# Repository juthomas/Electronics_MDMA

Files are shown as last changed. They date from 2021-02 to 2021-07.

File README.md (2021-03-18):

# MEGA DRINKING MACHINA ADVENTURE





<br/>

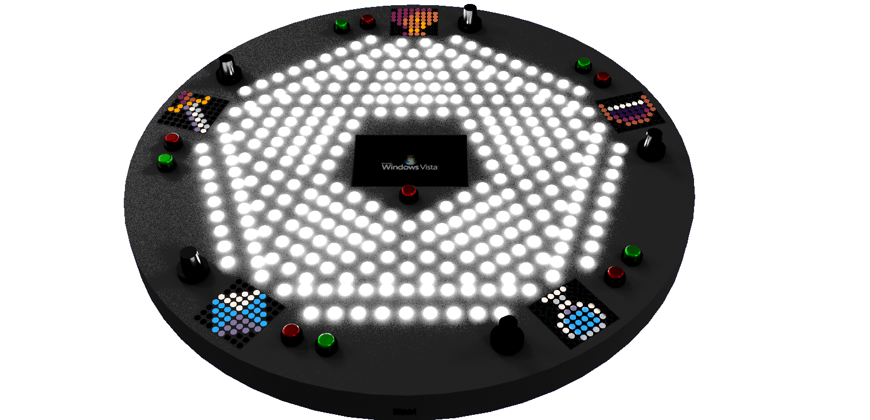
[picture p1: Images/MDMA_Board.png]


__Sommaire__ :
* [Description](#description)
* [Installation](#installation-avr)
* [Usage](#usage)
* [Visual Studio Code Linter](#visual-studio-code-linter)
* [Project Functionalities](#project-functionalities)
  * [Leds Control](#leds-control)
  * [Prerequisites](#prerequisites)
  * [Leds Variables](#leds-variables)
  * [Color Attribution](#color-attribution)
  * [Usefull Functions](#usefull-functions)

<div id='description'/>

## Description

Cet objet à été conçu sur les bases d’un témoignage perturbant à la date du 27 juin 2007 sur le forum ████ par l’utilisateur Chri████4.
Il y fait mention d’un jeu à boire avec ses amis où ils auraient décidé d'invoquer Satan aux alentours de 23h42. La soirée aurait tourné en une cruelle mission de subjugation du malin avec pour seule arme l’alcool en grande quantité qu’ils avaient préparé pour faire la fête. Suite à cette affaire le service d’exorcisme V-696 (avec à sa tête Jean-███II) aurait procédé à une énorme commande de Sobieski. 

À travers le projet Mega Drinking Machina Adventure™ nous voulons faire vivre à nos très chers futurs utilisateurs une simulation familiale de cette aventure hors du commun. Une compilation de jeux à boire allant de 1 à 5 joueurs sera proposée, avec une mise en place intuitive et rapide. Sur batterie, lumineux et facile à transporter, il deviendra votre meilleur outil pour pimenter vos soirées peu importe le contexte.
<div id='installation-avr'/>

## Installation (AVR)

* Debian Based Linux :  
  * Install avr-gcc :  
  `sudo apt-get install gcc-avr binutils-avr avr-libc`
  * Install avr-dude :  
  `sudo apt-get install avrdude`
* Macos Unix :  
  * Install brew (for noobies) :  
  `rm -rf $HOME/.brew && git clone --depth=1 https://github.com/Homebrew/brew $HOME/.brew && export PATH=$HOME/.brew/bin:$PATH && brew update && echo "export PATH=$HOME/.brew/bin:$PATH" >> ~/.zshrc`
  * Install avr-gcc :  
  `brew tap osx-cross/avr`  
  `brew install avr-gcc`
  * Install avr-dude :  
  `brew install avrdude`
<div id='usage'/>

## Usage

* Setup port :  
  `ls /dev/ > /tmp/file1`  
  then connect board  
  `ls /dev/ > /tmp/file2`  
  `diff /tmp/file1 /tmp/file2`  
  will give you the port  
  paste the given port to the `PORT` variable of the makefile

* Upload to board :  
  `make coffee` for build and upload  
  `make debug` for debuging  
  `make help` for other options
<div id='visual-studio-code-linter'/>

## Visual Studio Code Linter

* Install C/C++ extension  
* Configure C/C++ extension for avr :  
  Type `C/C++: Edit Configurations (JSON)` in Command Palette  
  * Linux :  
  Add `"/usr/lib/avr/include/**"` line to includePath  
  * Macos :  
  Add `"/Users/tmp/.brew/Cellar/avr-gcc@9/9.3.0_2/avr/include/**"`  
  on labelec macs  
  or  
  `/System/Volumes/Data/usr/local/Cellar/avr-gcc@9/9.3.0_2/avr/include/**`  
  (on real macs)  
  to includePath.  
  If this line doesnt work find "avr/io.h" file with `find / -name io.h`  
  Add the containing folder to includePath (like Linux method)

<div id='project-functionalities'/>

## Project Functionalities

<div id='leds-control'/>

### Leds Control

<div id='prerequisites'/>

#### Prerequisites
* `ft_pin_mode(led_pin, FT_OUTPUT);`

<div id='leds-variables'/>

#### Leds Variables
* char buffer (size = number of leds * 3)

<div id='color-attribution'/>

#### Color Attribution
  The color format is uint32_t : `0xLLRRGGBB`  
  LL : Luminosity (0x01 to 0xFF, or 0x00 to ignore)  
  RR : Red (0x00 to 0xFF)  
  GG : Green (0x00 to 0xFF)  
  BB : Blue (0x00 to 0xFF)  

<div id='usefull-functions'/>

#### Usefull Functions
* `uint8_t *feed_one_pixel(uint16_t pixel_index, uint8_t *pixels, uint32_t color)`  
  feed the selected pixel with the color
* `led_send_data(51, pixels, pixels_number);`  
  send data to the leds

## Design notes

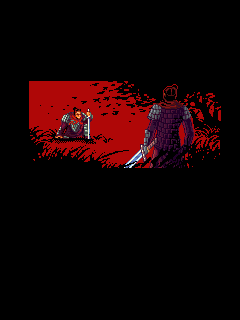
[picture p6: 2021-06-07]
Images/MDMA_Images/Duel.png

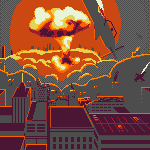
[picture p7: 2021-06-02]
Images/MDMA_Images/background tic.png

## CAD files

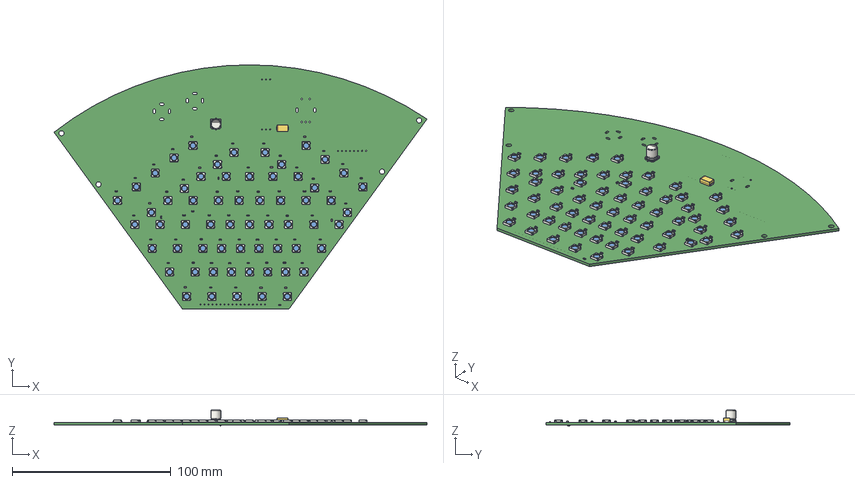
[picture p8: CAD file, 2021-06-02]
MDMA_KICAD_V2/MDMA/MDMA.step
235.0 x 153.9 x 9.85 mm

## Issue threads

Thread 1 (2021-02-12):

Cpu clock & time to execute in assembly

juthomas, 2021-02-12:
In makefile, F_CPU doesn't seems to change somethings, why?
In assembly some actions takes 0.083 us and others 0.1666 us, how and why?
(out %[portb], %[high])

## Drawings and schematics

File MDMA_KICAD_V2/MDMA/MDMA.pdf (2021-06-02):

LED_IN 5 MAT_IN 6 BUT_A 7 BUT_B 8 SW_ENC 9 P1Switch_Pin_out
IRQ 13 MISO 14 MOSI 15 SCK 16 CS 17 VCC_3.3 2 GND 3
VCC_5V 1 ROT_ENC_A 10 ROT_ENC_B 11 RST 12

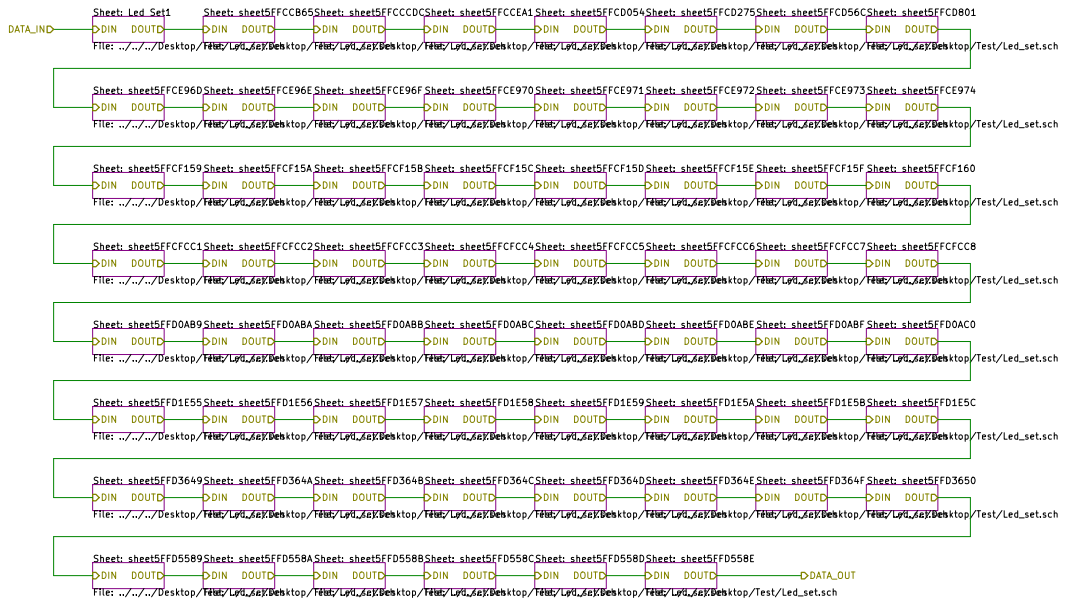
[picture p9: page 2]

Id: 2/66 Title: File: leds.sch Sheet: /leds/

File: Led_set.sch Sheet: /leds/Led Set1/
Id: 3/66 Title:

File: Led_set.sch Sheet: /leds/sheet5FFCCB65/
Id: 4/66 Title:

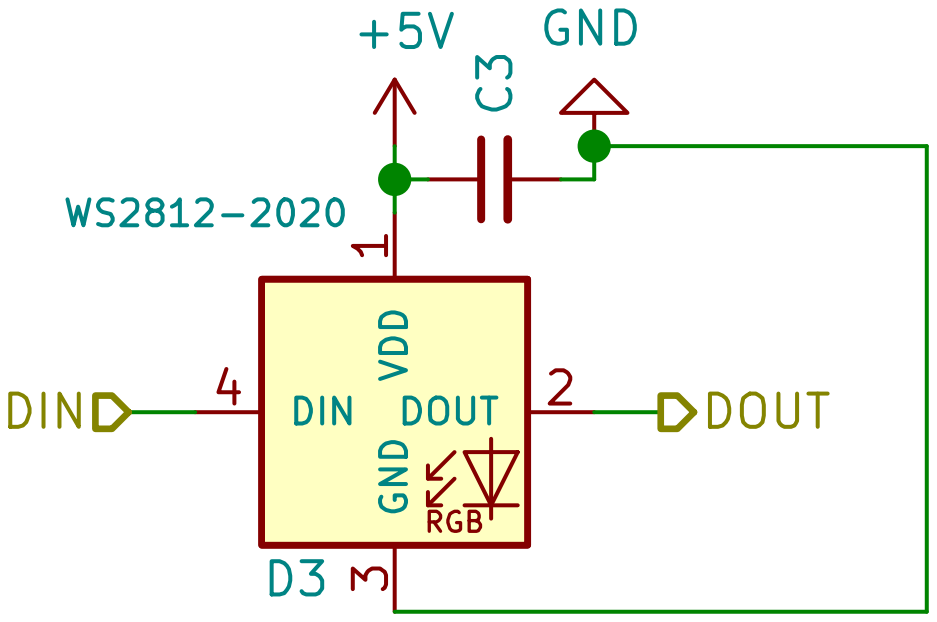
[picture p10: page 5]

File: Led_set.sch Sheet: /leds/sheet5FFCCCDC/
Id: 5/66 Title:

File: Led_set.sch Sheet: /leds/sheet5FFCCEA1/
Id: 6/66 Title:

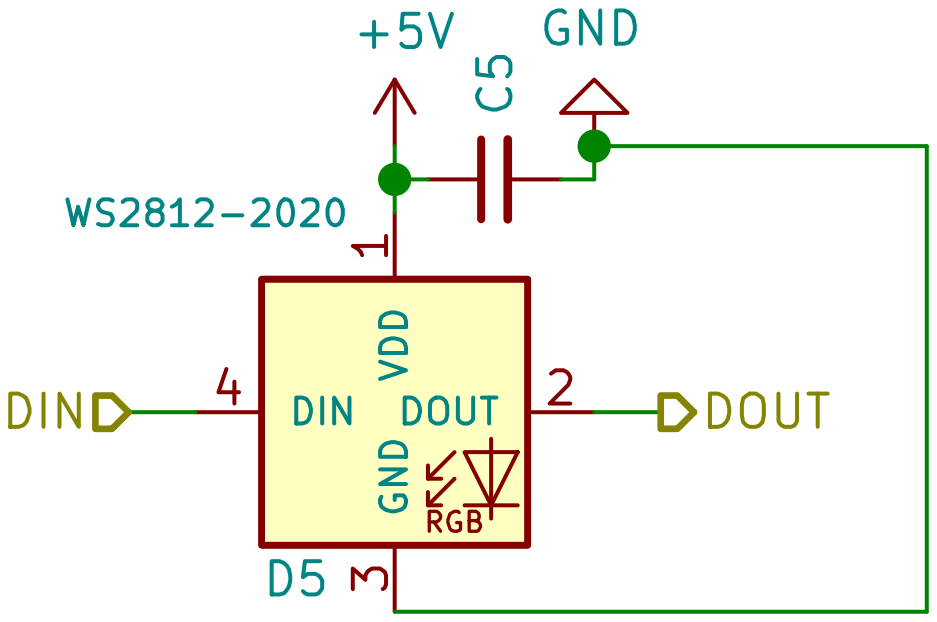
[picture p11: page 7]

File: Led_set.sch Sheet: /leds/sheet5FFCD054/
Id: 7/66 Title:

File: Led_set.sch Sheet: /leds/sheet5FFCD275/
Id: 8/66 Title:

File: Led_set.sch Sheet: /leds/sheet5FFCD56C/
Id: 9/66 Title:

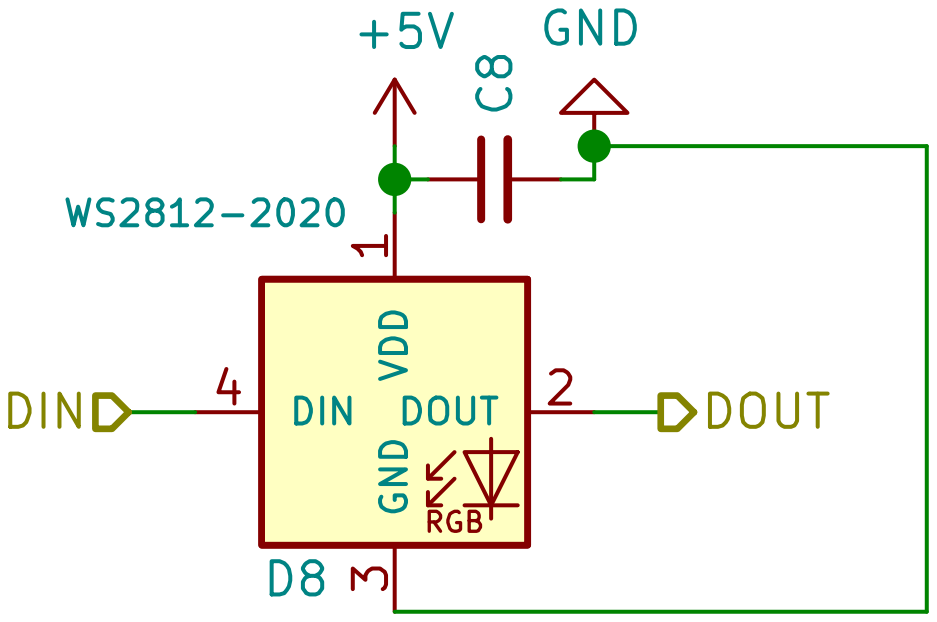
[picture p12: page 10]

File: Led_set.sch Sheet: /leds/sheet5FFCD801/
Id: 10/66 Title:

File: Led_set.sch Sheet: /leds/sheet5FFCE96D/
Id: 11/66 Title:

File: Led_set.sch Sheet: /leds/sheet5FFCE96E/
Id: 12/66 Title:

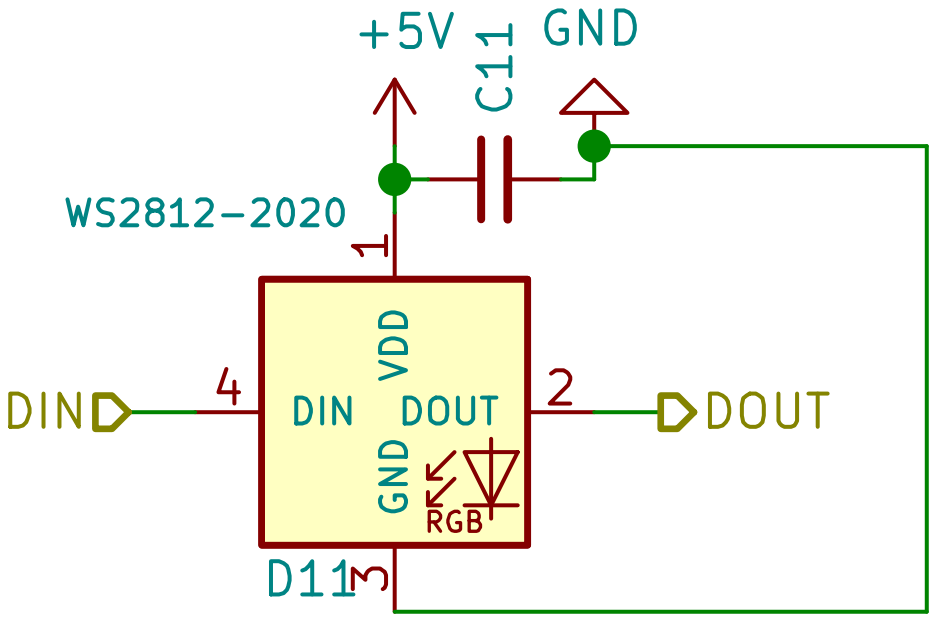
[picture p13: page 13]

File: Led_set.sch Sheet: /leds/sheet5FFCE96F/
Id: 13/66 Title:

File: Led_set.sch Sheet: /leds/sheet5FFCE970/
Id: 14/66 Title:

File: Led_set.sch Sheet: /leds/sheet5FFCE971/
Id: 15/66 Title:

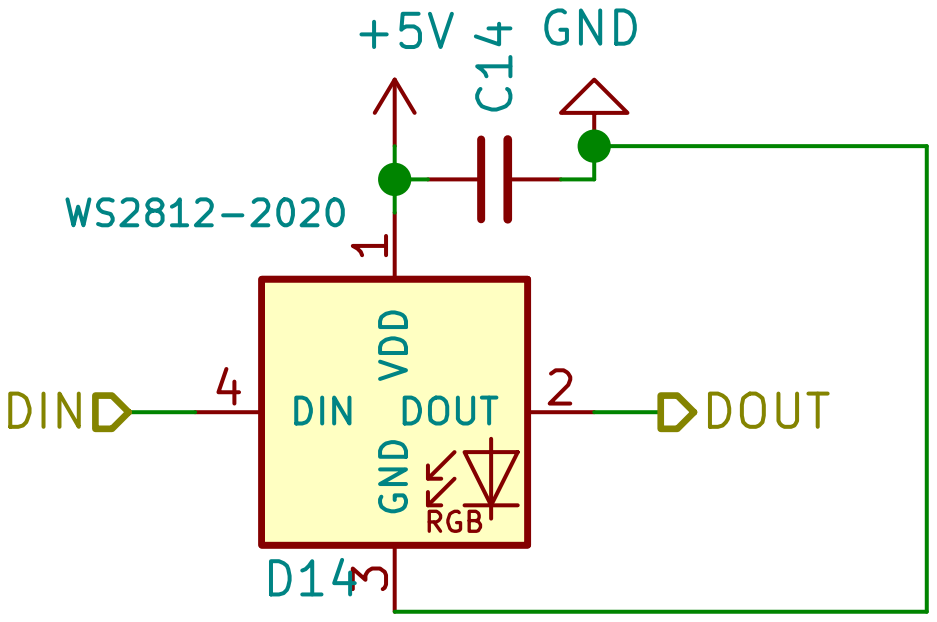
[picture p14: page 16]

File: Led_set.sch Sheet: /leds/sheet5FFCE972/
Id: 16/66 Title:

File: Led_set.sch Sheet: /leds/sheet5FFCE973/
Id: 17/66 Title:

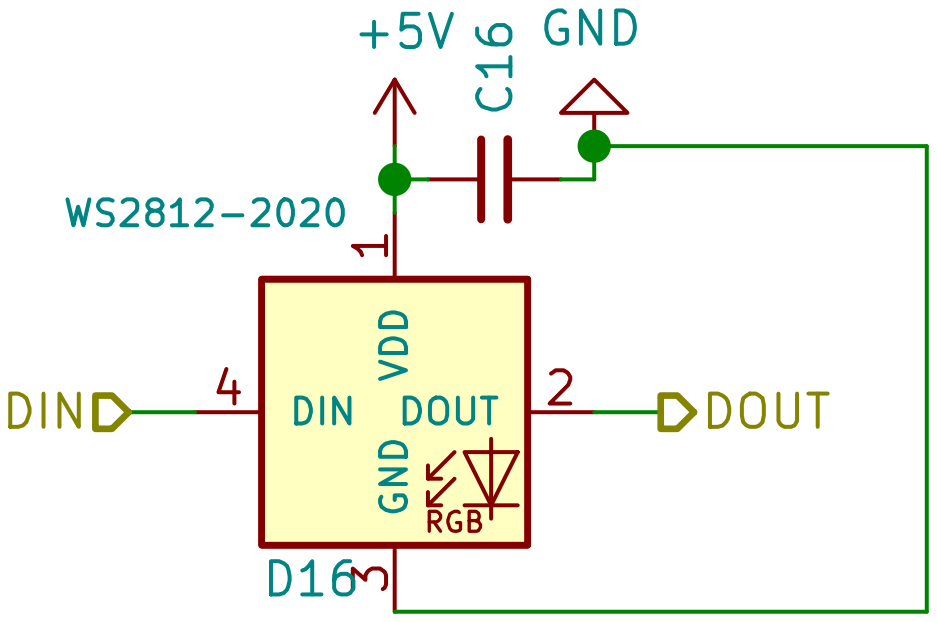
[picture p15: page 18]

File: Led_set.sch Sheet: /leds/sheet5FFCE974/
Id: 18/66 Title:

File: Led_set.sch Sheet: /leds/sheet5FFCF159/
Id: 19/66 Title:

File: Led_set.sch Sheet: /leds/sheet5FFCF15A/
Id: 20/66 Title:

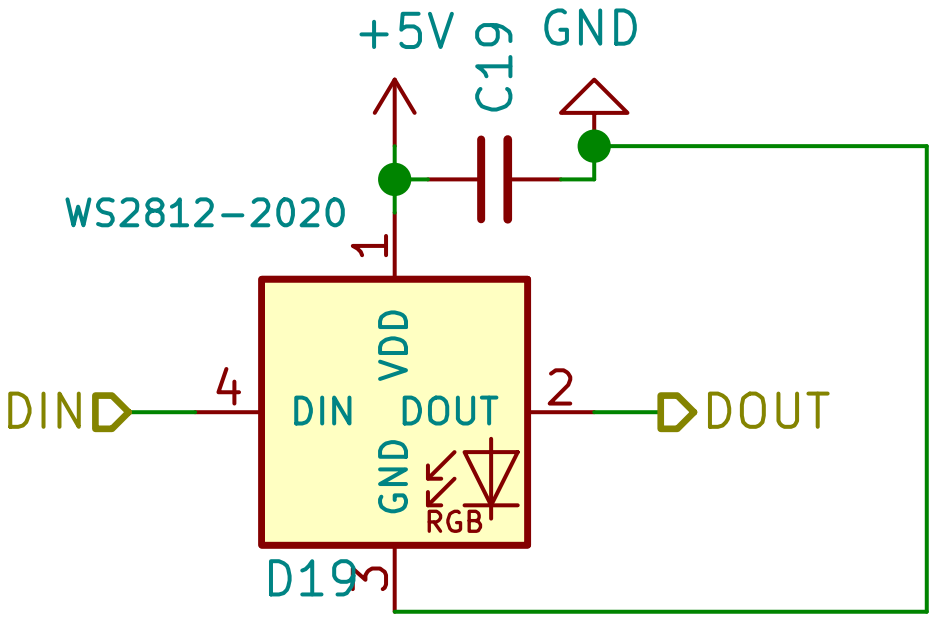
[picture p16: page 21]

File: Led_set.sch Sheet: /leds/sheet5FFCF15B/
Id: 21/66 Title:

File: Led_set.sch Sheet: /leds/sheet5FFCF15C/
Id: 22/66 Title:

File: Led_set.sch Sheet: /leds/sheet5FFCF15D/
Id: 23/66 Title:

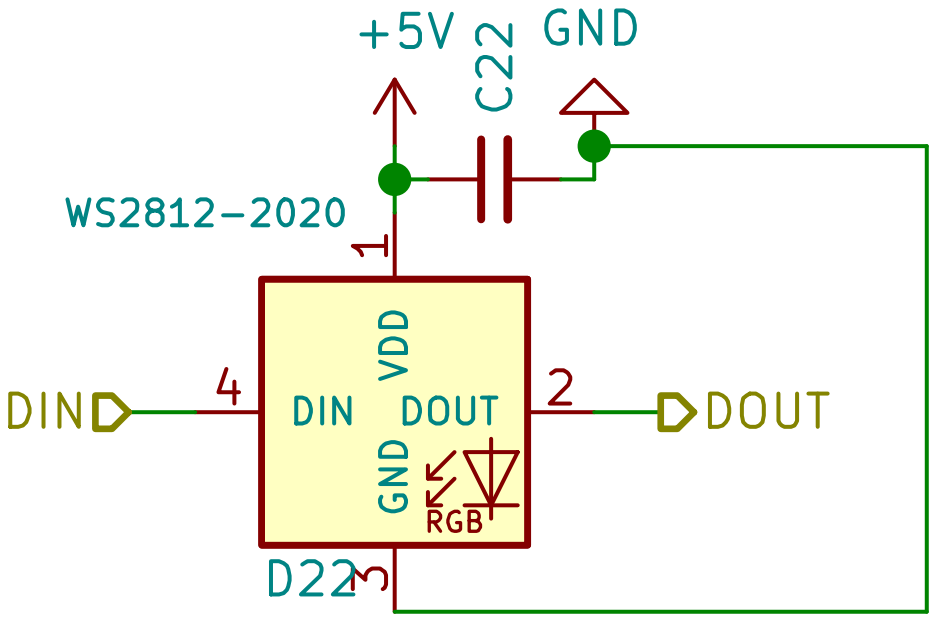
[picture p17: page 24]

File: Led_set.sch Sheet: /leds/sheet5FFCF15E/
Id: 24/66 Title:

File: Led_set.sch Sheet: /leds/sheet5FFCF15F/
Id: 25/66 Title:

File: Led_set.sch Sheet: /leds/sheet5FFCF160/
Id: 26/66 Title:

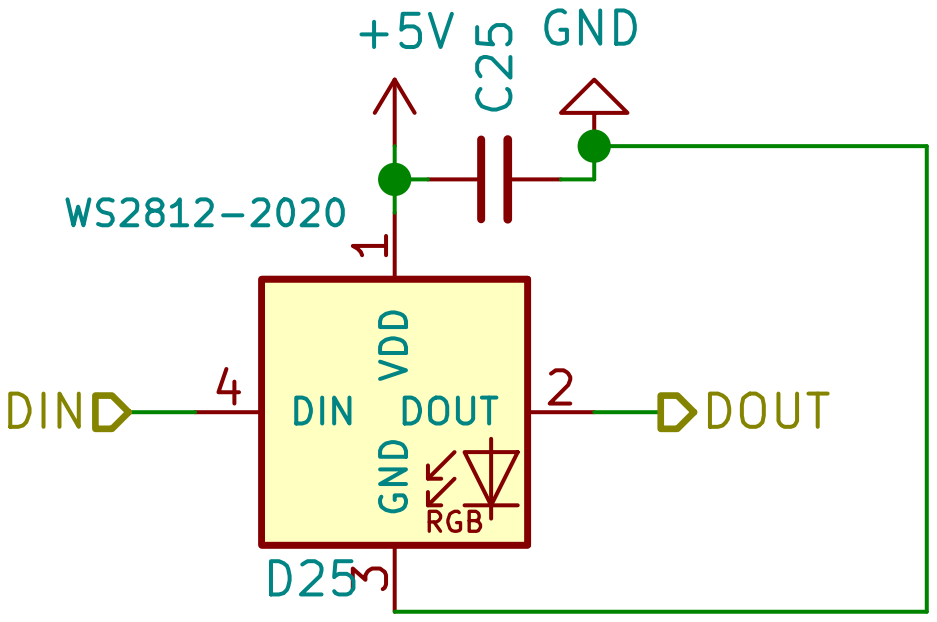
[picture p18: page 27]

File: Led_set.sch Sheet: /leds/sheet5FFCFCC1/
Id: 27/66 Title:

File: Led_set.sch Sheet: /leds/sheet5FFCFCC2/
Id: 28/66 Title:

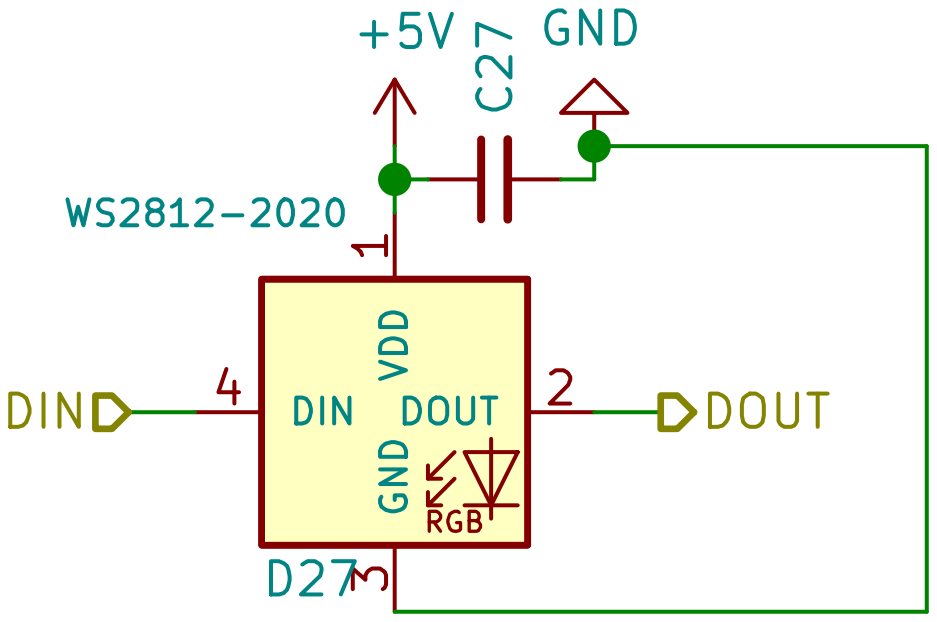
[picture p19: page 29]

File: Led_set.sch Sheet: /leds/sheet5FFCFCC3/
Id: 29/66 Title:

File: Led_set.sch Sheet: /leds/sheet5FFCFCC4/
Id: 30/66 Title:

File: Led_set.sch Sheet: /leds/sheet5FFCFCC5/
Id: 31/66 Title:

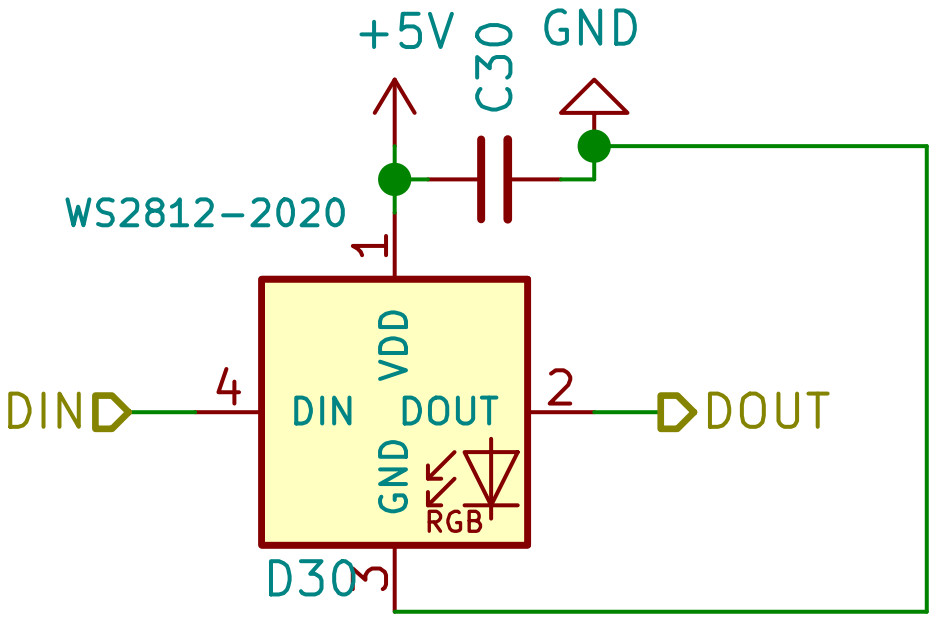
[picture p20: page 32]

File: Led_set.sch Sheet: /leds/sheet5FFCFCC6/
Id: 32/66 Title:

File: Led_set.sch Sheet: /leds/sheet5FFCFCC7/
Id: 33/66 Title:

File: Led_set.sch Sheet: /leds/sheet5FFCFCC8/
Id: 34/66 Title:


File: Led_set.sch Sheet: /leds/sheet5FFD0AB9/
Id: 35/66 Title:

File: Led_set.sch Sheet: /leds/sheet5FFD0ABA/
Id: 36/66 Title:

File: Led_set.sch Sheet: /leds/sheet5FFD0ABB/
Id: 37/66 Title:


File: Led_set.sch Sheet: /leds/sheet5FFD0ABC/
Id: 38/66 Title:

File: Led_set.sch Sheet: /leds/sheet5FFD0ABD/
Id: 39/66 Title:


File: Led_set.sch Sheet: /leds/sheet5FFD0ABE/
Id: 40/66 Title:

File: Led_set.sch Sheet: /leds/sheet5FFD0ABF/
Id: 41/66 Title:

File: Led_set.sch Sheet: /leds/sheet5FFD0AC0/
Id: 42/66 Title:


File: Led_set.sch Sheet: /leds/sheet5FFD1E55/
Id: 43/66 Title:

File: Led_set.sch Sheet: /leds/sheet5FFD1E56/
Id: 44/66 Title:

File: Led_set.sch Sheet: /leds/sheet5FFD1E57/
Id: 45/66 Title:


File: Led_set.sch Sheet: /leds/sheet5FFD1E58/
Id: 46/66 Title:

File: Led_set.sch Sheet: /leds/sheet5FFD1E59/
Id: 47/66 Title:

File: Led_set.sch Sheet: /leds/sheet5FFD1E5A/
Id: 48/66 Title:


File: Led_set.sch Sheet: /leds/sheet5FFD1E5B/
Id: 49/66 Title:

File: Led_set.sch Sheet: /leds/sheet5FFD1E5C/
Id: 50/66 Title:


File: Led_set.sch Sheet: /leds/sheet5FFD3649/
Id: 51/66 Title:

File: Led_set.sch Sheet: /leds/sheet5FFD364A/
Id: 52/66 Title:

File: Led_set.sch Sheet: /leds/sheet5FFD364B/
Id: 53/66 Title:


File: Led_set.sch Sheet: /leds/sheet5FFD364C/
Id: 54/66 Title:

File: Led_set.sch Sheet: /leds/sheet5FFD364D/
Id: 55/66 Title:

File: Led_set.sch Sheet: /leds/sheet5FFD364E/
Id: 56/66 Title:


File: Led_set.sch Sheet: /leds/sheet5FFD364F/
Id: 57/66 Title:

File: Led_set.sch Sheet: /leds/sheet5FFD3650/
Id: 58/66 Title:

File: Led_set.sch Sheet: /leds/sheet5FFD5589/
Id: 59/66 Title:


File: Led_set.sch Sheet: /leds/sheet5FFD558A/
Id: 60/66 Title:

File: Led_set.sch Sheet: /leds/sheet5FFD558B/
Id: 61/66 Title:
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

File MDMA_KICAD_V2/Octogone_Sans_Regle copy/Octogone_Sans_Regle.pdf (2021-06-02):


Alimentation
RX Player Input Parts
Sheet: sheet6073AE66 File: Pizza_Pin_In.sch ENC_A

LED_OUT MISO MOSI CLK RST CS

File: Pizza_Pin_In.sch ENC_A
USB Type C to Serial

2 SCK 3 MOSI 4 RST 5 GND


LVHV HV1 Sheet: sheet60A33480 File: level_shifter.sch

File: SPI_Level_Shifter.sch Sheet: /Sheet60A2DFDA/ Sheet: sheet60A30133 File: level_shifter.sch





IRQ 13 MISO 14 MOSI 15 SCK 16 CS 17 VCC_3.3 2 GND 3




IRQ 13 MISO 14 MOSI 15 SCK 16 CS 17 VCC_3.3 2 GND 3




IRQ 13 MISO 14 MOSI 15 SCK 16 CS 17 VCC_3.3 2 GND 3




IRQ 13 MISO 14 MOSI 15 SCK 16 CS 17 VCC_3.3 2 GND 3




IRQ 13 MISO 14 MOSI 15 SCK 16 CS 17 VCC_3.3 2 GND 3






























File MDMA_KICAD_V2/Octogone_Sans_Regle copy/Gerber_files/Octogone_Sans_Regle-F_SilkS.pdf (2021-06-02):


CS RST DC MOSI CLK

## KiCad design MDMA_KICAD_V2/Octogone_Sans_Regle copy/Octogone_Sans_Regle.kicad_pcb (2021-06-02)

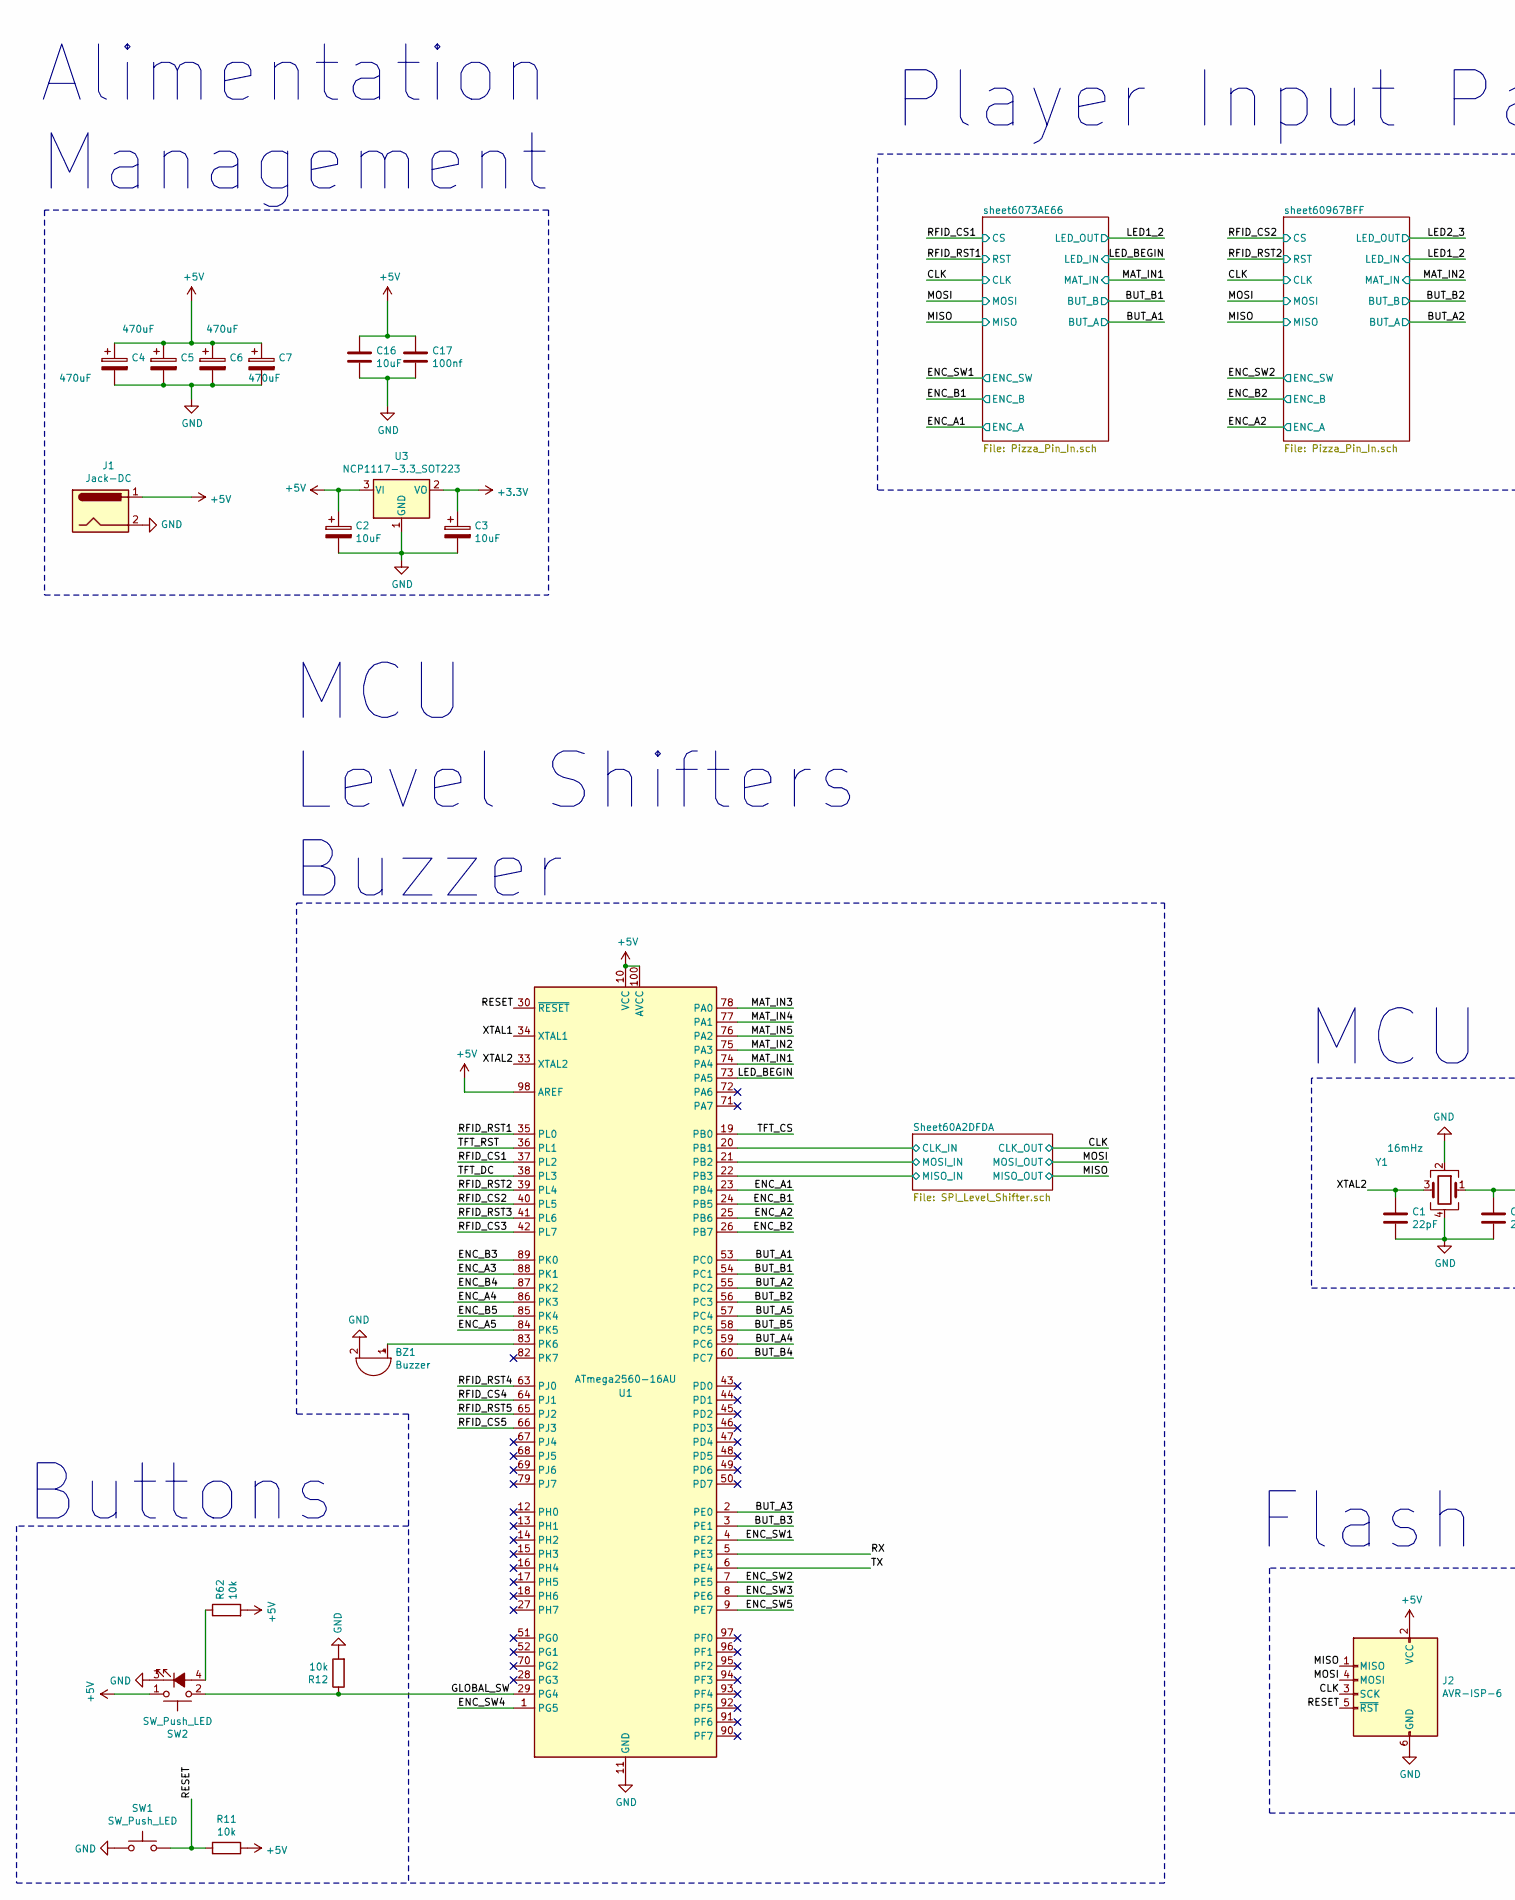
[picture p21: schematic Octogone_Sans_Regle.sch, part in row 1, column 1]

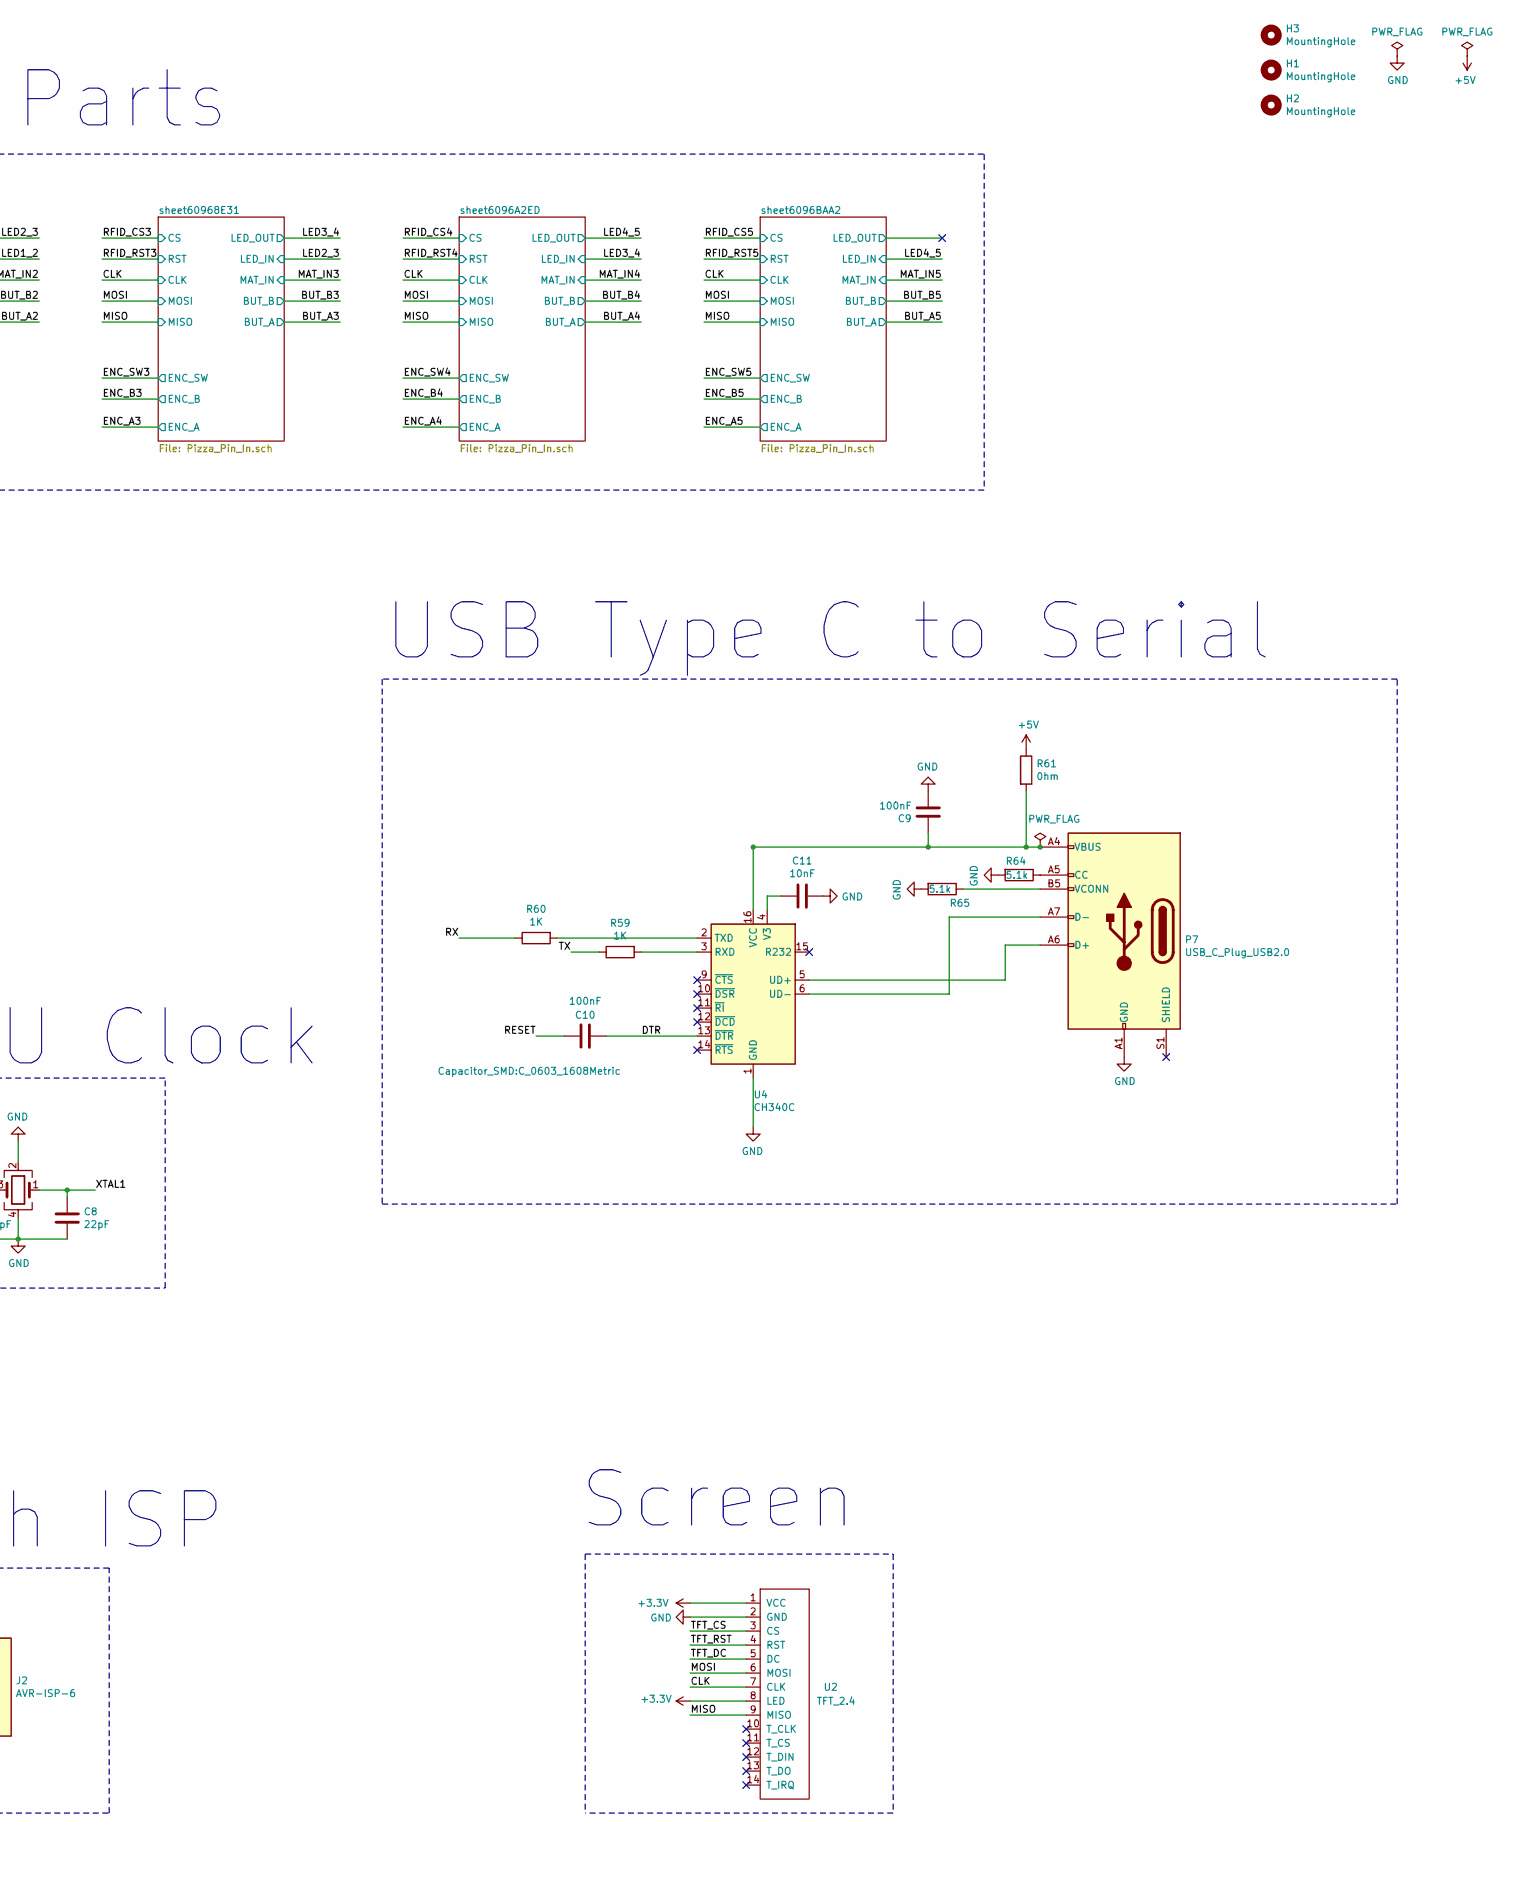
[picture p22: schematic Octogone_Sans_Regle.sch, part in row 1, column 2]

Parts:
BZ1: Buzzer; Buzzer_12x9.5RM7.6
C1, C8: 22pF; C_0603_1608Metric
C2, C3: 10uF; CP_EIA-3216-18_Kemet-A
C4, C5, C6, C7: 470uF; CP_EIA-7343-30_AVX-N
C9, C10: 100nF; C_0603_1608Metric
C11: 10nF; C_0603_1608Metric
C16: 10uF; C_0603_1608Metric
C17: 100nf; C_0603_1608Metric
H1, H2, H3: MountingHole; MountingHole_3.2mm_M3
J1: Jack-DC; BarrelJack_Horizontal
J2: AVR-ISP-6; Connector_SPI_6
P7: USB_C_Plug_USB2.0; USB_C_Receptacle_HRO_TYPE-C-31-M-12
R11, R12, R62: 10k; R_0603_1608Metric
R59, R60: 1K; R_0603_1608Metric
R61: 0hm; R_0603_1608Metric
R64, R65: 5.1k; R_0603_1608Metric
SW1: SW_Push_LED; Switch_4x3
SW2: SW_Push_LED; SW_LED_16mm
U1: ATmega2560-16AU; TQFP-100_14x14mm_P0.5mm
U2: TFT_2.4; TFT_Connector
U3: NCP1117-3.3_SOT223; SOT-223-3_TabPin2
U4: CH340C; SOIC-16_3.9x9.9mm_P1.27mm
Y1: 16mHz; crystal

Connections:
+3V3: C3.1, U2.1 (VCC), U2.8 (LED), U3.2 (VO); also elsewhere on the board
+5V: C2.1, C4.1, C5.1, C6.1, C7.1, C16.1, C17.1, J1.1, J2.2 (VCC), R11.1, R61.1, R62.2, SW2.1, U1.10 (VCC), U1.31 (VCC), U1.61 (VCC), U1.80 (VCC), U1.98 (AREF), U1.100 (AVCC), U3.3 (VI); also elsewhere on the board
/BUT_A1: U1.53 (PC0); also elsewhere on the board
/BUT_A2: U1.55 (PC2); also elsewhere on the board
/BUT_A3: U1.2 (PE0); also elsewhere on the board
/BUT_A4: U1.59 (PC6); also elsewhere on the board
/BUT_A5: U1.57 (PC4); also elsewhere on the board
/BUT_B1: U1.54 (PC1); also elsewhere on the board
/BUT_B2: U1.56 (PC3); also elsewhere on the board
/BUT_B3: U1.3 (PE1); also elsewhere on the board
/BUT_B4: U1.60 (PC7); also elsewhere on the board
/BUT_B5: U1.58 (PC5); also elsewhere on the board
/CLK: J2.3 (SCK), U2.7 (CLK); also elsewhere on the board
/DTR: C10.2, U4.13 (~DTR)
/ENC_A1: U1.23 (PB4); also elsewhere on the board
/ENC_A2: U1.25 (PB6); also elsewhere on the board
/ENC_A3: U1.88 (PK1); also elsewhere on the board
/ENC_A4: U1.86 (PK3); also elsewhere on the board
/ENC_A5: U1.84 (PK5); also elsewhere on the board
/ENC_B1: U1.24 (PB5); also elsewhere on the board
/ENC_B2: U1.26 (PB7); also elsewhere on the board
/ENC_B3: U1.89 (PK0); also elsewhere on the board
/ENC_B4: U1.87 (PK2); also elsewhere on the board
/ENC_B5: U1.85 (PK4); also elsewhere on the board
/ENC_SW1: U1.4 (PE2); also elsewhere on the board
/ENC_SW2: U1.7 (PE5); also elsewhere on the board
/ENC_SW3: U1.8 (PE6); also elsewhere on the board
/ENC_SW4: U1.1 (PG5); also elsewhere on the board
/ENC_SW5: U1.9 (PE7); also elsewhere on the board
/GLOBAL_SW: R12.1, SW2.2, U1.29 (PG4)
/LED_BEGIN: U1.73 (PA5); also elsewhere on the board
/MAT_IN1: U1.74 (PA4); also elsewhere on the board
/MAT_IN2: U1.75 (PA3); also elsewhere on the board
/MAT_IN3: U1.78 (PA0); also elsewhere on the board
/MAT_IN4: U1.77 (PA1); also elsewhere on the board
/MAT_IN5: U1.76 (PA2); also elsewhere on the board
/MISO: J2.1 (MISO), U2.9 (MISO); also elsewhere on the board
/MOSI: J2.4 (MOSI), U2.6 (MOSI); also elsewhere on the board
/RESET: C10.1, J2.5 (~RST), R11.2, SW1.2, U1.30 (~RESET)
/RFID_CS1: U1.37 (PL2); also elsewhere on the board
/RFID_CS2: U1.40 (PL5); also elsewhere on the board
/RFID_CS3: U1.42 (PL7); also elsewhere on the board
/RFID_CS4: U1.64 (PJ1); also elsewhere on the board
/RFID_CS5: U1.66 (PJ3); also elsewhere on the board
/RFID_RST1: U1.35 (PL0); also elsewhere on the board
/RFID_RST2: U1.39 (PL4); also elsewhere on the board
/RFID_RST3: U1.41 (PL6); also elsewhere on the board
/RFID_RST4: U1.63 (PJ0); also elsewhere on the board
/RFID_RST5: U1.65 (PJ2); also elsewhere on the board
/RX: R60.1, U1.5 (PE3)
/Sheet60A2DFDA/CLK_IN: U1.20 (PB1); also elsewhere on the board
/Sheet60A2DFDA/MISO_IN: U1.22 (PB3); also elsewhere on the board
/Sheet60A2DFDA/MOSI_IN: U1.21 (PB2); also elsewhere on the board
/TFT_CS: U1.19 (PB0), U2.3 (CS)
/TFT_DC: U1.38 (PL3), U2.5 (DC)
/TFT_RST: U1.36 (PL1), U2.4 (RST)
/TX: R59.1, U1.6 (PE4)
/XTAL1: C8.1, U1.34 (XTAL1), Y1.1
/XTAL2: C1.1, U1.33 (XTAL2), Y1.3
GND: BZ1.2 (+), C1.2, C2.2, C3.2, C4.2, C5.2, C6.2, C7.2, C8.2, C9.2, C11.2, C16.2, C17.2, J1.2, J2.6 (GND), P7.A1 (GND), P7.A12 (GND), P7.B1 (GND), P7.B12 (GND), R12.2, R64.2, R65.2, SW1.1, SW2.3 (K), U1.11 (GND), U1.32 (GND), U1.62 (GND), U1.81 (GND), U1.99 (GND), U2.2 (GND), U3.1 (GND), U4.1 (GND), Y1.2, Y1.4; also elsewhere on the board
unnamed: BZ1.1 (-), U1.83 (PK6)
unnamed: C9.1, P7.A4 (VBUS), P7.A9 (VBUS), P7.B4 (VBUS), P7.B9 (VBUS), R61.2, U4.16 (VCC)
unnamed: C11.1, U4.4 (V3)
unnamed: P7.A5 (CC), R64.1
unnamed: P7.A6 (D+), U4.5 (UD+)
unnamed: P7.A7 (D-), U4.6 (UD-)
unnamed: P7.B5 (VCONN), R65.1
unnamed: R59.2, U4.3 (RXD)
unnamed: R60.2, U4.2 (TXD)
unnamed: R62.1, SW2.4 (A)

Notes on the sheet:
Player Input Parts
USB Type C to Serial
Screen
Alimentation Management
MCU Clock
Buttons
Flash ISP
MCU Level Shifters Buzzer

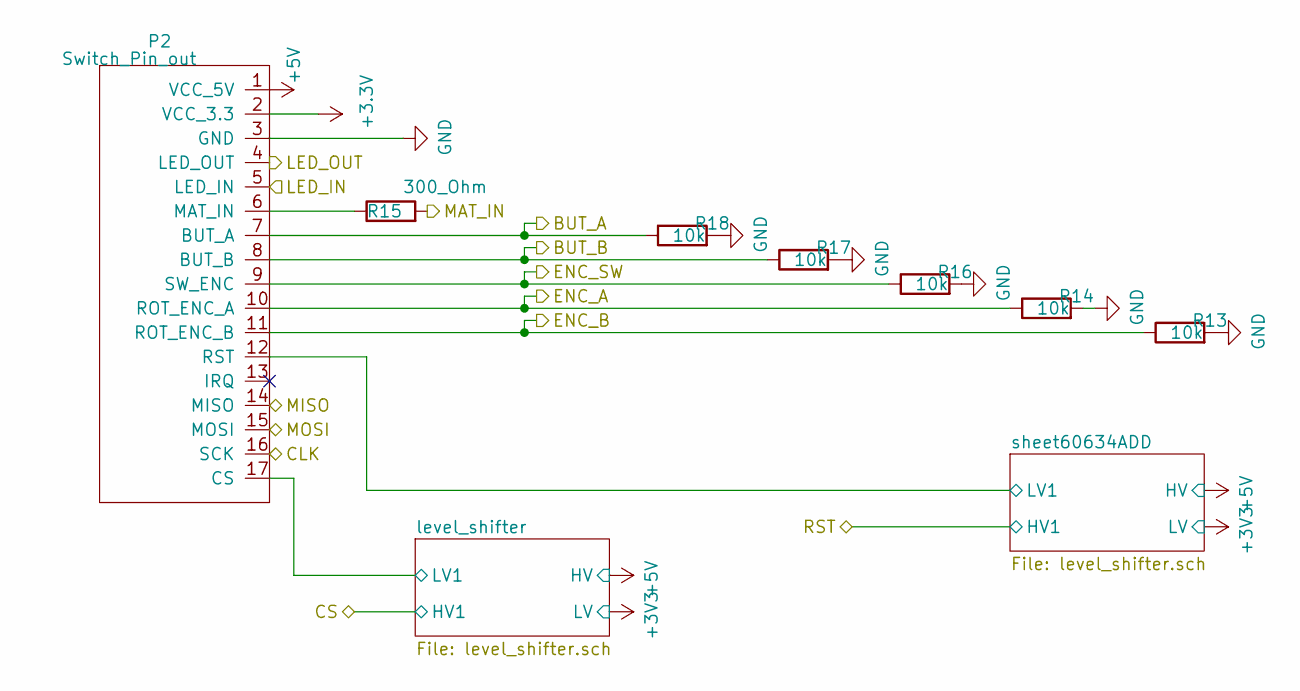
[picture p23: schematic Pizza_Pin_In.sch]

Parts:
P1: Switch_Pin_out; Pizza_Pin_Out
R1, R2, R4, R5, R6: 10k; R_0603_1608Metric
R3: 300_Ohm; R_0603_1608Metric

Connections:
+3V3: P1.2 (VCC_3.3); also elsewhere on the board
+5V: P1.1 (VCC_5V); also elsewhere on the board
/BUT_A1: P1.7 (BUT_A), R6.1; also elsewhere on the board
/BUT_B1: P1.8 (BUT_B), R5.1; also elsewhere on the board
/CLK: P1.16 (SCK); also elsewhere on the board
/ENC_A1: P1.10 (ROT_ENC_A), R2.1; also elsewhere on the board
/ENC_B1: P1.11 (ROT_ENC_B), R1.1; also elsewhere on the board
/ENC_SW1: P1.9 (SW_ENC), R4.1; also elsewhere on the board
/LED1_2: P1.4 (LED_OUT); also elsewhere on the board
/LED_BEGIN: P1.5 (LED_IN); also elsewhere on the board
/MAT_IN1: R3.2; also elsewhere on the board
/MISO: P1.14 (MISO); also elsewhere on the board
/MOSI: P1.15 (MOSI); also elsewhere on the board
/sheet6073AE66/level_shifter/LV1: P1.17 (CS); also elsewhere on the board
/sheet6073AE66/sheet60634ADD/LV1: P1.12 (RST); also elsewhere on the board
GND: P1.3 (GND), R1.2, R2.2, R4.2, R5.2, R6.2; also elsewhere on the board
unnamed: P1.6 (MAT_IN), R3.1

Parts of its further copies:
P2, P3, P4, P5: Switch_Pin_out; Pizza_Pin_Out
R13, R14, R16, R17, R18, R23, R24, R26, R27, R28, R39, R40, R42, R43, R44, R49, R50, R52, R53, R54: 10k; R_0603_1608Metric
R15, R25, R41, R51: 300_Ohm; R_0603_1608Metric

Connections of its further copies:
+3V3: P2.2 (VCC_3.3), P3.2 (VCC_3.3), P4.2 (VCC_3.3), P5.2 (VCC_3.3); also elsewhere on the board
+5V: P2.1 (VCC_5V), P3.1 (VCC_5V), P4.1 (VCC_5V), P5.1 (VCC_5V); also elsewhere on the board
/BUT_A2: P5.7 (BUT_A), R54.1; also elsewhere on the board
/BUT_A3: P2.7 (BUT_A), R18.1; also elsewhere on the board
/BUT_A4: P3.7 (BUT_A), R28.1; also elsewhere on the board
/BUT_A5: P4.7 (BUT_A), R44.1; also elsewhere on the board
/BUT_B2: P5.8 (BUT_B), R53.1; also elsewhere on the board
/BUT_B3: P2.8 (BUT_B), R17.1; also elsewhere on the board
/BUT_B4: P3.8 (BUT_B), R27.1; also elsewhere on the board
/BUT_B5: P4.8 (BUT_B), R43.1; also elsewhere on the board
/CLK: P2.16 (SCK), P3.16 (SCK), P4.16 (SCK), P5.16 (SCK); also elsewhere on the board
/ENC_A2: P5.10 (ROT_ENC_A), R50.1; also elsewhere on the board
/ENC_A3: P2.10 (ROT_ENC_A), R14.1; also elsewhere on the board
/ENC_A4: P3.10 (ROT_ENC_A), R24.1; also elsewhere on the board
/ENC_A5: P4.10 (ROT_ENC_A), R40.1; also elsewhere on the board
/ENC_B2: P5.11 (ROT_ENC_B), R49.1; also elsewhere on the board
/ENC_B3: P2.11 (ROT_ENC_B), R13.1; also elsewhere on the board
/ENC_B4: P3.11 (ROT_ENC_B), R23.1; also elsewhere on the board
/ENC_B5: P4.11 (ROT_ENC_B), R39.1; also elsewhere on the board
/ENC_SW2: P5.9 (SW_ENC), R52.1; also elsewhere on the board
/ENC_SW3: P2.9 (SW_ENC), R16.1; also elsewhere on the board
/ENC_SW4: P3.9 (SW_ENC), R26.1; also elsewhere on the board
/ENC_SW5: P4.9 (SW_ENC), R42.1; also elsewhere on the board
/LED1_2: P5.5 (LED_IN); also elsewhere on the board
/LED2_3: P2.5 (LED_IN), P5.4 (LED_OUT)
/LED3_4: P2.4 (LED_OUT), P3.5 (LED_IN)
/LED4_5: P3.4 (LED_OUT), P4.5 (LED_IN)
/MAT_IN2: R51.2; also elsewhere on the board
/MAT_IN3: R15.2; also elsewhere on the board
/MAT_IN4: R25.2; also elsewhere on the board
/MAT_IN5: R41.2; also elsewhere on the board
/MISO: P2.14 (MISO), P3.14 (MISO), P4.14 (MISO), P5.14 (MISO); also elsewhere on the board
/MOSI: P2.15 (MOSI), P3.15 (MOSI), P4.15 (MOSI), P5.15 (MOSI); also elsewhere on the board
/sheet6096A2ED/level_shifter/LV1: P3.17 (CS); also elsewhere on the board
/sheet6096A2ED/sheet60634ADD/LV1: P3.12 (RST); also elsewhere on the board
/sheet6096BAA2/level_shifter/LV1: P4.17 (CS); also elsewhere on the board
/sheet6096BAA2/sheet60634ADD/LV1: P4.12 (RST); also elsewhere on the board
/sheet60967BFF/level_shifter/LV1: P5.17 (CS); also elsewhere on the board
/sheet60967BFF/sheet60634ADD/LV1: P5.12 (RST); also elsewhere on the board
/sheet60968E31/level_shifter/LV1: P2.17 (CS); also elsewhere on the board
/sheet60968E31/sheet60634ADD/LV1: P2.12 (RST); also elsewhere on the board
GND: P2.3 (GND), P3.3 (GND), P4.3 (GND), P5.3 (GND), R13.2, R14.2, R16.2, R17.2, R18.2, R23.2, R24.2, R26.2, R27.2, R28.2, R39.2, R40.2, R42.2, R43.2, R44.2, R49.2, R50.2, R52.2, R53.2, R54.2; also elsewhere on the board
unnamed: P2.6 (MAT_IN), R15.1
unnamed: P3.6 (MAT_IN), R25.1
unnamed: P4.6 (MAT_IN), R41.1
unnamed: P5.6 (MAT_IN), R51.1

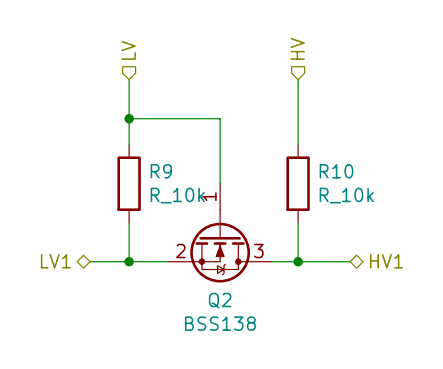
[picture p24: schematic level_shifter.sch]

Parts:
Q1: BSS138; SOT-23
R7, R8: R_10k; R_0603_1608Metric

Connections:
+3V3: Q1.1 (G), R7.1; also elsewhere on the board
+5V: R8.1; also elsewhere on the board
/RFID_CS1: Q1.3 (D), R8.2; also elsewhere on the board
/sheet6073AE66/level_shifter/LV1: Q1.2 (S), R7.2; also elsewhere on the board

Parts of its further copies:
Q2, Q3, Q4, Q5, Q6, Q7, Q8, Q9, Q10, Q11, Q12, Q13, Q14: BSS138; SOT-23
R9, R10, R19, R20, R21, R22, R29, R30, R31, R32, R33, R34, R35, R36, R37, R38, R45, R46, R47, R48, R55, R56, R57, R58: R_10k; R_0603_1608Metric

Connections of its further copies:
+3V3: Q2.1 (G), Q4.1 (G), Q5.1 (G), Q6.1 (G), Q7.1 (G), Q8.1 (G), Q9.1 (G), Q10.1 (G), Q11.1 (G), Q12.1 (G), Q13.1 (G), Q14.1 (G), R9.1, R19.1, R21.1, R29.1, R31.1, R33.1, R35.1, R37.1, R45.1, R47.1, R55.1, R57.1; also elsewhere on the board
+5V: R10.1, R20.1, R22.1, R30.1, R32.1, R34.1, R36.1, R38.1, R46.1, R48.1, R56.1, R58.1; also elsewhere on the board
/CLK: Q8.2 (S), R33.2; also elsewhere on the board
/MISO: Q10.2 (S), R37.2; also elsewhere on the board
/MOSI: Q9.2 (S), R35.2; also elsewhere on the board
/RFID_CS2: Q13.3 (D), R56.2; also elsewhere on the board
/RFID_CS3: Q4.3 (D), R20.2; also elsewhere on the board
/RFID_CS4: Q6.3 (D), R30.2; also elsewhere on the board
/RFID_CS5: Q11.3 (D), R46.2; also elsewhere on the board
/RFID_RST1: Q2.3 (D), R10.2; also elsewhere on the board
/RFID_RST2: Q14.3 (D), R58.2; also elsewhere on the board
/RFID_RST3: Q5.3 (D), R22.2; also elsewhere on the board
/RFID_RST4: Q7.3 (D), R32.2; also elsewhere on the board
/RFID_RST5: Q12.3 (D), R48.2; also elsewhere on the board
/Sheet60A2DFDA/CLK_IN: Q8.3 (D), R34.2; also elsewhere on the board
/Sheet60A2DFDA/MISO_IN: Q10.3 (D), R38.2; also elsewhere on the board
/Sheet60A2DFDA/MOSI_IN: Q9.3 (D), R36.2; also elsewhere on the board
/sheet6073AE66/sheet60634ADD/LV1: Q2.2 (S), R9.2; also elsewhere on the board
/sheet6096A2ED/level_shifter/LV1: Q6.2 (S), R29.2; also elsewhere on the board
/sheet6096A2ED/sheet60634ADD/LV1: Q7.2 (S), R31.2; also elsewhere on the board
/sheet6096BAA2/level_shifter/LV1: Q11.2 (S), R45.2; also elsewhere on the board
/sheet6096BAA2/sheet60634ADD/LV1: Q12.2 (S), R47.2; also elsewhere on the board
/sheet60967BFF/level_shifter/LV1: Q13.2 (S), R55.2; also elsewhere on the board
/sheet60967BFF/sheet60634ADD/LV1: Q14.2 (S), R57.2; also elsewhere on the board
/sheet60968E31/level_shifter/LV1: Q4.2 (S), R19.2; also elsewhere on the board
/sheet60968E31/sheet60634ADD/LV1: Q5.2 (S), R21.2; also elsewhere on the board

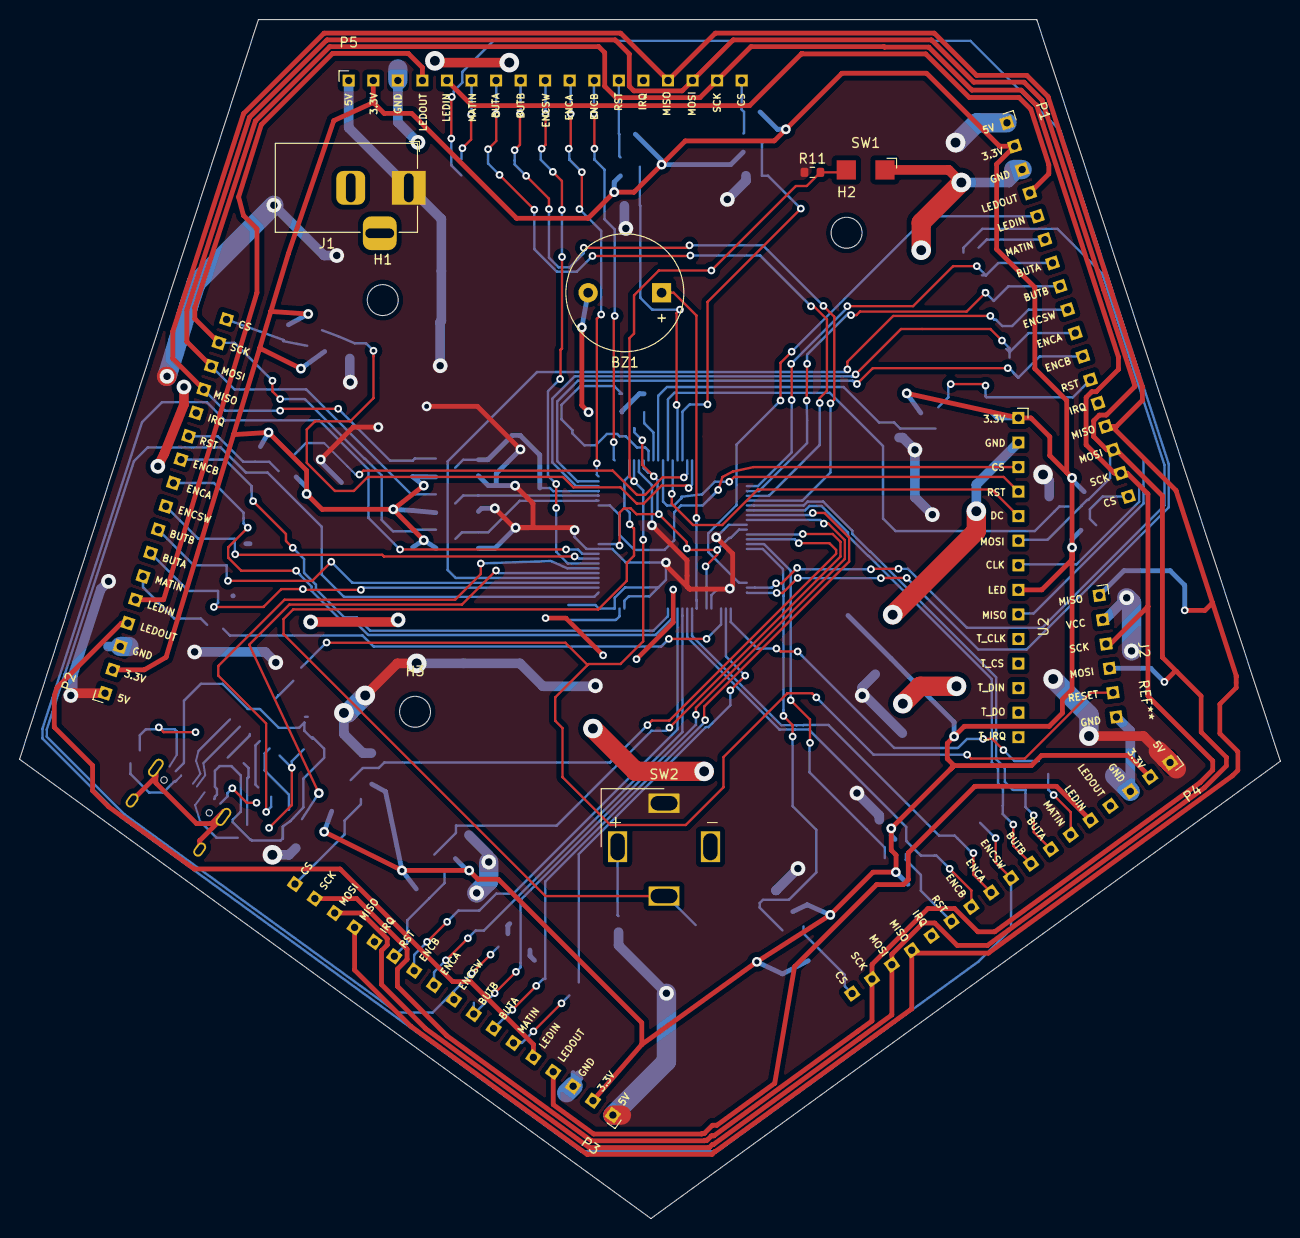
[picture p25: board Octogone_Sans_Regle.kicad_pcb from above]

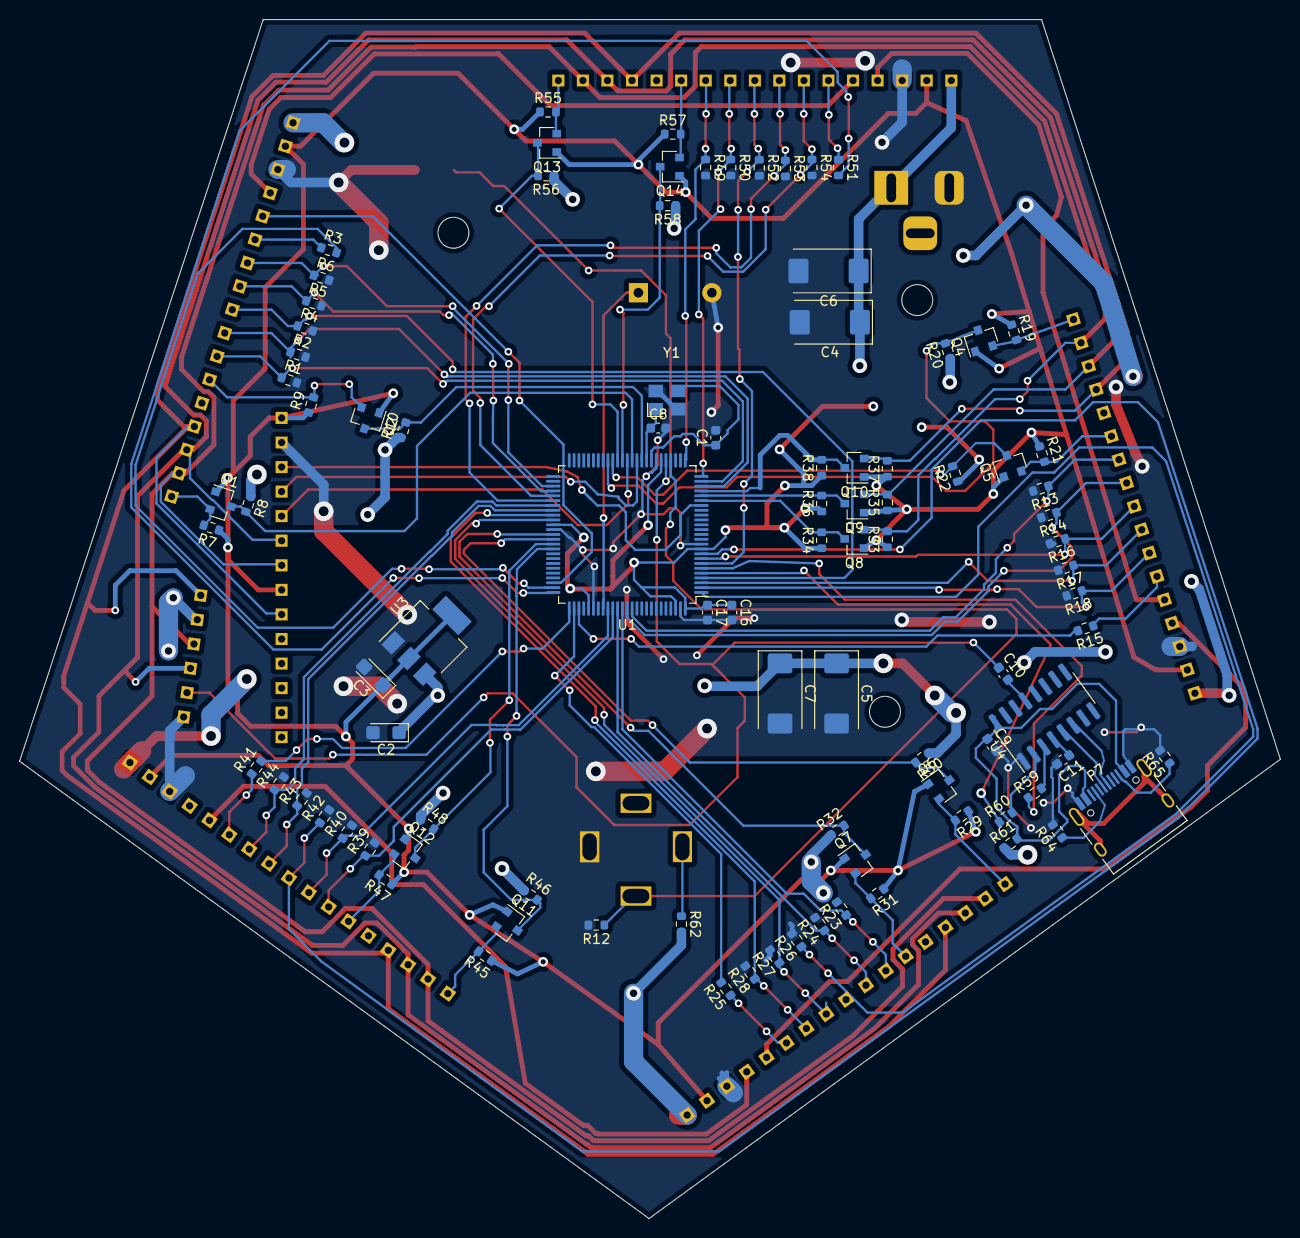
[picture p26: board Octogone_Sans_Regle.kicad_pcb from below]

Board: 2 copper layers, 130.4 x 124.0 mm, 109 parts (94 on the bottom side), 89 nets.

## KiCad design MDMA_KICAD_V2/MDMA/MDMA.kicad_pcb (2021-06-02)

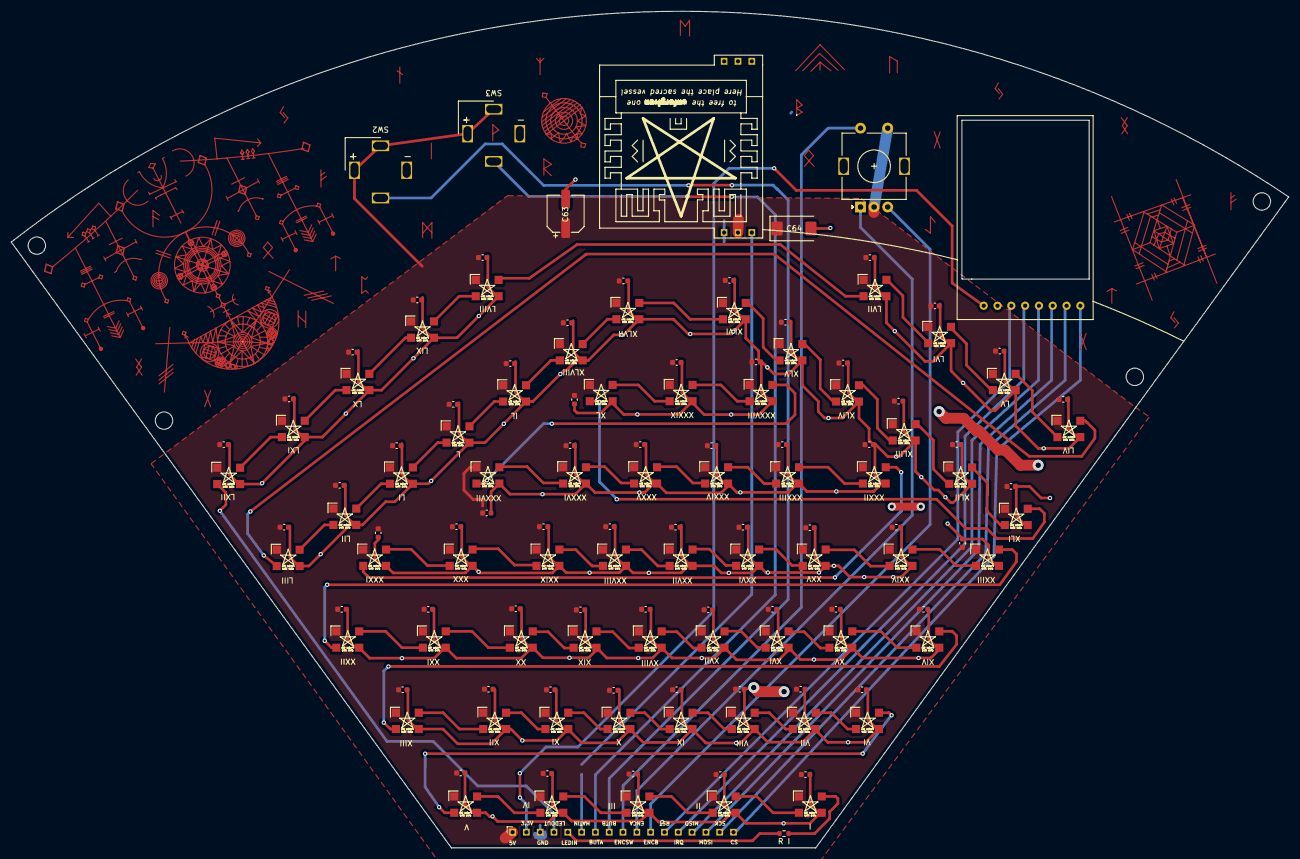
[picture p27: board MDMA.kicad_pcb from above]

Board: 2 copper layers, 235.0 x 153.9 mm, 138 parts (1 on the bottom side), 80 nets.

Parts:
C1, C2, C3, C4, C5, C6, C7, C8, C9, C10, C11, C12, C13, C14, C15, C16, C17, C18, C19, C20, C21, C22, C23, C24, C25, C26, C27, C28, C29, C30, C31, C32, C33, C34, C35, C36, C37, C38, C39, C40, C41, C42, C43, C44, C45, C46, C47, C48, C49, C50, C51, C52, C53, C54, C55, C56, C57, C58, C59, C60, C61, C62: 100nF; C_0603_1608Metric
C63: 470uF; CP_Elec_6.3x7.7
C64: 470uf; CP_EIA-7343-30_AVX-N
H1, H2, H3, H4: MountingHole; MountingHole_3.2mm_M3
I: WS2812-2020; WS2812B
II: WS2812-2020; WS2812B
III: WS2812-2020; WS2812B
IL: WS2812-2020; WS2812B
IV: WS2812-2020; WS2812B
IX: WS2812-2020; WS2812B
L: WS2812-2020; WS2812B
LI: WS2812-2020; WS2812B
LII: WS2812-2020; WS2812B
LIII: WS2812-2020; WS2812B
LIV: WS2812-2020; WS2812B
LIX: WS2812-2020; WS2812B
LV: WS2812-2020; WS2812B
LVI: WS2812-2020; WS2812B
LVII: WS2812-2020; WS2812B
LVIII: WS2812-2020; WS2812B
LX: WS2812-2020; WS2812B
LXI: WS2812-2020; WS2812B
LXII: WS2812-2020; WS2812B
P1: Switch_Pin_out; Pizza_Pin_Out
R I: 300/0 Ohm; R_0603_1608Metric
R II: 300 Ohm; R_0603_1608Metric
SW1: Rotary_Encoder_Switch; RotaryEncoder_Alps_EC11E-Switch_Vertical_H20mm
SW2, SW3: SW_Push_LED; SW_LED_16mm
T1: RFID_Module; RFID_RC522
U1: Matrice8x8_WS2812
V: WS2812-2020; WS2812B
VI: WS2812-2020; WS2812B
VII: WS2812-2020; WS2812B
VIII: WS2812-2020; WS2812B
X: WS2812-2020; WS2812B
XI: WS2812-2020; WS2812B
XII: WS2812-2020; WS2812B
XIII: WS2812-2020; WS2812B
XIV: WS2812-2020; WS2812B
XIX: WS2812-2020; WS2812B
XL: WS2812-2020; WS2812B
XLI: WS2812-2020; WS2812B
XLII: WS2812-2020; WS2812B
XLIII: WS2812-2020; WS2812B
XLIV: WS2812-2020; WS2812B
XLV: WS2812-2020; WS2812B
XLVI: WS2812-2020; WS2812B
XLVII: WS2812-2020; WS2812B
XLVIII: WS2812-2020; WS2812B
XV: WS2812-2020; WS2812B
XVI: WS2812-2020; WS2812B
XVII: WS2812-2020; WS2812B
XVIII: WS2812-2020; WS2812B
XX: WS2812-2020; WS2812B
XXI: WS2812-2020; WS2812B
XXII: WS2812-2020; WS2812B
XXIII: WS2812-2020; WS2812B
XXIV: WS2812-2020; WS2812B
XXIX: WS2812-2020; WS2812B
XXV: WS2812-2020; WS2812B
XXVI: WS2812-2020; WS2812B
XXVII: WS2812-2020; WS2812B
XXVIII: WS2812-2020; WS2812B
XXX: WS2812-2020; WS2812B
XXXI: WS2812-2020; WS2812B
XXXII: WS2812-2020; WS2812B
XXXIII: WS2812-2020; WS2812B
XXXIV: WS2812-2020; WS2812B
XXXIX: WS2812-2020; WS2812B
XXXV: WS2812-2020; WS2812B
XXXVI: WS2812-2020; WS2812B
XXXVII: WS2812-2020; WS2812B
XXXVIII: WS2812-2020; WS2812B

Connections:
+3V3: P1.2, T1.1
+5V: C1.1, C2.1, C3.1, C4.1, C5.1, C6.1, C7.1, C8.1, C9.1, C10.1, C11.1, C12.1, C13.1, C14.1, C15.1, C16.1, C17.1, C18.1, C19.1, C20.1, C21.1, C22.1, C23.1, C24.1, C25.1, C26.1, C27.1, C28.1, C29.1, C30.1, C31.1, C32.1, C33.1, C34.1, C35.1, C36.1, C37.1, C38.1, C39.1, C40.1, C41.1, C42.1, C43.1, C44.1, C45.1, C46.1, C47.1, C48.1, C49.1, C50.1, C51.1, C52.1, C53.1, C54.1, C55.1, C56.1, C57.1, C58.1, C59.1, C60.1, C61.1, C62.1, C63.1, C64.1, I.1, II.1, III.1, IL.1, IV.1, IX.1, L.1, LI.1, LII.1, LIII.1, LIV.1, LIX.1, LV.1, LVI.1, LVII.1, LVIII.1, LX.1, LXI.1, LXII.1, P1.1, SW1.C, SW1.S1, SW2.1, SW2.4, SW3.1, SW3.4, U1.2, V.1, VI.1, VII.1, VIII.1, X.1, XI.1, XII.1, XIII.1, XIV.1, XIX.1, XL.1, XLI.1, XLII.1, XLIII.1, XLIV.1, XLV.1, XLVI.1, XLVII.1, XLVIII.1, XV.1, XVI.1, XVII.1, XVIII.1, XX.1, XXI.1, XXII.1, XXIII.1, XXIV.1, XXIX.1, XXV.1, XXVI.1, XXVII.1, XXVIII.1, XXX.1, XXXI.1, XXXII.1, XXXIII.1, XXXIV.1, XXXIX.1, XXXV.1, XXXVI.1, XXXVII.1, XXXVIII.1
/leds/DATA_IN: I.4, R I.1
/leds/DATA_OUT: LXII.2, P1.4
/leds/sheet5FFCCB65/DIN: I.2, II.4
/leds/sheet5FFCCCDC/DIN: II.2, III.4
/leds/sheet5FFCCEA1/DIN: III.2, IV.4
/leds/sheet5FFCD054/DIN: IV.2, V.4
/leds/sheet5FFCD56C/DIN: VI.2, VII.4
/leds/sheet5FFCD275/DIN: V.2, VI.4
/leds/sheet5FFCD801/DIN: VII.2, VIII.4
/leds/sheet5FFCE96D/DIN: IX.4, VIII.2
/leds/sheet5FFCE96E/DIN: IX.2, X.4
/leds/sheet5FFCE96F/DIN: X.2, XI.4
/leds/sheet5FFCE970/DIN: XI.2, XII.4
/leds/sheet5FFCE971/DIN: XII.2, XIII.4
/leds/sheet5FFCE972/DIN: XIII.2, XIV.4
/leds/sheet5FFCE973/DIN: XIV.2, XV.4
/leds/sheet5FFCE974/DIN: XV.2, XVI.4
/leds/sheet5FFCF15A/DIN: XVII.2, XVIII.4
/leds/sheet5FFCF15B/DIN: XIX.4, XVIII.2
/leds/sheet5FFCF15C/DIN: XIX.2, XX.4
/leds/sheet5FFCF15D/DIN: XX.2, XXI.4
/leds/sheet5FFCF15E/DIN: XXI.2, XXII.4
/leds/sheet5FFCF15F/DIN: XXII.2, XXIII.4
/leds/sheet5FFCF159/DIN: XVI.2, XVII.4
/leds/sheet5FFCF160/DIN: XXIII.2, XXIV.4
/leds/sheet5FFCFCC1/DIN: XXIV.2, XXV.4
/leds/sheet5FFCFCC2/DIN: XXV.2, XXVI.4
/leds/sheet5FFCFCC3/DIN: XXVI.2, XXVII.4
/leds/sheet5FFCFCC4/DIN: XXVII.2, XXVIII.4
/leds/sheet5FFCFCC5/DIN: XXIX.4, XXVIII.2
/leds/sheet5FFCFCC6/DIN: XXIX.2, XXX.4
/leds/sheet5FFCFCC7/DIN: XXX.2, XXXI.4
/leds/sheet5FFCFCC8/DIN: XXXI.2, XXXII.4
/leds/sheet5FFD0AB9/DIN: XXXII.2, XXXIII.4
/leds/sheet5FFD0ABA/DIN: XXXIII.2, XXXIV.4
/leds/sheet5FFD0ABB/DIN: XXXIV.2, XXXV.4
/leds/sheet5FFD0ABC/DIN: XXXV.2, XXXVI.4
/leds/sheet5FFD0ABD/DIN: XXXVI.2, XXXVII.4
/leds/sheet5FFD0ABE/DIN: XXXVII.2, XXXVIII.4
/leds/sheet5FFD0ABF/DIN: XXXIX.4, XXXVIII.2
/leds/sheet5FFD0AC0/DIN: XL.4, XXXIX.2
/leds/sheet5FFD1E5A/DIN: XLV.2, XLVI.4
/leds/sheet5FFD1E5B/DIN: XLVI.2, XLVII.4
/leds/sheet5FFD1E5C/DIN: XLVII.2, XLVIII.4
/leds/sheet5FFD1E55/DIN: XL.2, XLI.4
/leds/sheet5FFD1E56/DIN: XLI.2, XLII.4
/leds/sheet5FFD1E57/DIN: XLII.2, XLIII.4
/leds/sheet5FFD1E58/DIN: XLIII.2, XLIV.4
/leds/sheet5FFD1E59/DIN: XLIV.2, XLV.4
/leds/sheet5FFD364A/DIN: IL.2, L.4
/leds/sheet5FFD364B/DIN: L.2, LI.4
/leds/sheet5FFD364C/DIN: LI.2, LII.4
/leds/sheet5FFD364D/DIN: LII.2, LIII.4
/leds/sheet5FFD364E/DIN: LIII.2, LIV.4
/leds/sheet5FFD364F/DIN: LIV.2, LV.4
/leds/sheet5FFD558A/DIN: LVII.2, LVIII.4
/leds/sheet5FFD558B/DIN: LIX.4, LVIII.2
/leds/sheet5FFD558C/DIN: LIX.2, LX.4
/leds/sheet5FFD558D/DIN: LX.2, LXI.4
/leds/sheet5FFD558E/DIN: LXI.2, LXII.4
/leds/sheet5FFD3649/DIN: IL.4, XLVIII.2
/leds/sheet5FFD3650/DIN: LV.2, LVI.4
/leds/sheet5FFD5589/DIN: LVI.2, LVII.4
/switch_led2/SW_OUTPUT: P1.7, SW3.2
/switch_led/SW_OUTPUT: P1.8, SW2.2
GND: C1.2, C2.2, C3.2, C4.2, C5.2, C6.2, C7.2, C8.2, C9.2, C10.2, C11.2, C12.2, C13.2, C14.2, C15.2, C16.2, C17.2, C18.2, C19.2, C20.2, C21.2, C22.2, C23.2, C24.2, C25.2, C26.2, C27.2, C28.2, C29.2, C30.2, C31.2, C32.2, C33.2, C34.2, C35.2, C36.2, C37.2, C38.2, C39.2, C40.2, C41.2, C42.2, C43.2, C44.2, C45.2, C46.2, C47.2, C48.2, C49.2, C50.2, C51.2, C52.2, C53.2, C54.2, C55.2, C56.2, C57.2, C58.2, C59.2, C60.2, C61.2, C62.2, C63.2, C64.2, I.3, II.3, III.3, IL.3, IV.3, IX.3, L.3, LI.3, LII.3, LIII.3, LIV.3, LIX.3, LV.3, LVI.3, LVII.3, LVIII.3, LX.3, LXI.3, LXII.3, P1.3, SW2.3, SW3.3, T1.2, U1.3, V.3, VI.3, VII.3, VIII.3, X.3, XI.3, XII.3, XIII.3, XIV.3, XIX.3, XL.3, XLI.3, XLII.3, XLIII.3, XLIV.3, XLV.3, XLVI.3, XLVII.3, XLVIII.3, XV.3, XVI.3, XVII.3, XVIII.3, XX.3, XXI.3, XXII.3, XXIII.3, XXIV.3, XXIX.3, XXV.3, XXVI.3, XXVII.3, XXVIII.3, XXX.3, XXXI.3, XXXII.3, XXXIII.3, XXXIV.3, XXXIX.3, XXXV.3, XXXVI.3, XXXVII.3, XXXVIII.3
unnamed: P1.5, R I.2
unnamed: P1.6, R II.2
unnamed: P1.9, SW1.S2
unnamed: P1.10, SW1.A
unnamed: P1.11, SW1.B
unnamed: P1.12, T1.3
unnamed: P1.13, T1.4
unnamed: P1.14, T1.5
unnamed: P1.15, T1.6
unnamed: P1.16, T1.7
unnamed: P1.17, T1.8
unnamed: R II.1, U1.1

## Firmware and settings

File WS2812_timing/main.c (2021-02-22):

#ifndef __AVR_ATmega328P__
# define __AVR_ATmega328P__
#endif
#include "avr/io.h"
#include "avr/interrupt.h"
//https://www.codeproject.com/Articles/15971/Using-Inline-Assembly-in-C-C
//https://developer.arm.com/documentation/100748/0606/Using-Assembly-and-Intrinsics-in-C-or-C---Code/Writing-inline-assembly-code
//https://stackoverflow.com/questions/36560646/r-vs-r-assembly-clarification

// pour le truc de "I" _SFR_IO_ADDR(PORT)
//https://www.avrfreaks.net/forum/undefined-reference-pre-pro-symbols-asm
int main()
{

	volatile uint8_t red = 255;
	volatile uint8_t green = 255;
	volatile uint8_t blue = 255;
	volatile uint8_t registerLowMask = 0b00000000;//ancien registre + etat haut pin
	volatile uint8_t registerHighMask = 0b00000011;//ancien registre + etat bas pin
	volatile uint8_t output = 0;
	cli();
	DDRB |= (1 << 0);
	DDRB |= (1 << 1);
	for (;;)
	{
		PORTB = 0b00000001;//~= 0.33us
		PORTB = 0b00000000;//~= 0.33us 

		PORTB = 0b00000001;
		PORTB = 0b00000000;

		PORTB = 0b00000001;
		PORTB = 0b00000000;

		PORTB = 0b00000001;
		PORTB = 0b00000000;

		asm volatile(
			// ".INCLUDE \"8515def.inc\"\n"
			// "out %[portb], %[low]  \n"//
			// "out %[portb], %[high] \n"//~= 0.08333us
			// "out %[portb], %[high] \n"//~= 0.08333us+0.08333us // fait un "bas haut" chelou
			// "out %[portb], %[high] \n"//~= 0.08333us+0.08333us // fait un "bas haut" chelou
			// "out %[portb], %[high] \n"//~= 0.08333us+0.08333us // fait un "bas haut" chelou
			// "out %[portb], %[high] \n"//~= 0.08333us+0.08333us // fait un "bas haut" chelou
			// "out %[portb], %[low]  \n"//~= 0.1666us
			// "out %[portb], %[high] \n"
			"out %[portb], %[low]  \n"
			"out %[portb], %[low]  \n"
			"out %[portb], %[high] \n"
			"out %[portb], %[low]  \n"
			"out %[portb], %[low]  \n"
			"out %[portb], %[high] \n"
			"out %[portb], %[low]  \n"
			"out %[portb], %[low]  \n"
			"out %[portb], %[high] \n"
			"out %[portb], %[low]  \n"
			"out %[portb], %[low]  \n"
			"out %[portb], %[high] \n"
			"out %[portb], %[low]  \n"
			"out %[portb], %[high] \n"
			"out %[portb], %[low]  \n"
			"out %[portb], %[high] \n"
			"out %[portb], %[low]  \n"
			"out %[portb], %[high] \n"
			"out %[portb], %[low]  \n"
			"out %[portb], %[high] \n"
			"out %[portb], %[low]  \n"
			"out %[portb], %[high] \n"
			"out %[portb], %[low]  \n"
			"out %[portb], %[high] \n"
			"out %[portb], %[low]  \n"
			"out %[portb], %[high] \n"
			"out %[portb], %[low]  \n"
			"out %[portb], %[high] \n"
			"out %[portb], %[low]  \n"
			"out %[portb], %[high] \n"
			"out %[portb], %[low]  \n"
			"out %[portb], %[high] \n"
			"out %[portb], %[low]  \n"
			"out %[portb], %[high] \n"
			"out %[portb], %[low]  \n"
			"out %[portb], %[high] \n"
			"out %[portb], %[low]  \n"
			"out %[portb], %[high] \n"
			: :
			[red] "r" (red),
			[green] "r" (green),
			[blue] "r" (blue),
			[low] "r" (registerLowMask),
			[high] "r" (registerHighMask),
			[portb] "I" (_SFR_IO_ADDR(PORTB))
		);


	}
	sei();
	return (0);
}

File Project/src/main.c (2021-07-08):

#include <avr/io.h>
#include "../inc/mdma.h"
#include "../inc/tone.h"
#include "../inc/leds.h"
#include "../inc/buttons.h"
//#include "../inc/matrix_progmem.h"
#include "../inc/millis.h"
#include "../inc/encoders.h"

#define CPU_CLOCK 2000000

void draw_buttons(uint8_t *led_buffer)
{
	uint32_t interactions_color = 0x090909;
	// draw_satanic_circle();
	clear_led_buffer(led_buffer, 62 * 3 * 5, 0x090000);

	if (buttons_clicks_order[15])
	{
		draw_cirle_pit(led_buffer, 500, 5, D_WAWES, LED_ROW_1, interactions_color, 0x090000);
	}
	for (int i = 0; i < 5; i++)
	{
		if (buttons_clicks_order[i * 3])
		{
			draw_line_between_players(led_buffer, ((i + 0) % 5) + 1, ((i + 1) % 5) + 1,
									  FALSE, interactions_color);
		}
		led_send_data_PORTA(1 << PIN5, led_buffer, 62 * 5);
		if (buttons_clicks_order[i * 3 + 1])
		{
			draw_line_between_players(led_buffer, ((i + 0) % 5) + 1, ((i + 4) % 5) + 1,
									  FALSE, interactions_color);
		}
		if (buttons_clicks_order[i * 3 + 2])
		{
			draw_line_between_players(led_buffer, ((i + 0) % 5) + 1, ((i + 2) % 5) + 1,
									  FALSE, interactions_color);
		}
	}
	led_send_data_PORTA(1 << PIN5, led_buffer, 62 * 5);
}

int main()
{
	init_millis();
	uint8_t led_buffer[62 * 3 * 5];
	init_buttons();
	init_encoders();
	init_leds(led_buffer);
	clear_led_buffer(led_buffer, 62 * 3 * 5, 0x000000);
	led_send_data_PORTA(MAT_1 | MAT_3 | MAT_4 | MAT_2 | MAT_5 | 1 << PIN5, led_buffer, 62 * 3 * 5);

	initSPI();

	ili9341_begin();
	while (1)
	{
		ili9341_fillScreen(ILI9341_BLACK);
		start_game(led_buffer);
	}
	return (0);
}

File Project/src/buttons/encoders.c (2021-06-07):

#include "../../inc/encoders.h"
#ifndef __AVR_ATmega2560__
#define __AVR_ATmega2560__
#define F_CPU 16000000
#endif
#include <avr/io.h>
#include <avr/interrupt.h>
#include <stdint.h>
#include "../../inc/millis.h"

static uint8_t old_state[5] = {0, 0, 0, 0, 0};

void encoders_state(uint8_t now, uint8_t index)
{
	if ((old_state[index] == 0 && now == 2) || (old_state[index] == 2 && now == 3) \
	|| (old_state[index] == 3 && now == 1) || (old_state[index] == 1 && now == 0))
	{
		encoders[index]++;
	}
	else if (((old_state[index] == 0 && now == 1) || (old_state[index] == 2 && now == 0) \
	|| (old_state[index] == 3 && now == 2) || (old_state[index] == 1 && now == 3)))
	{
		encoders[index]--;
	}
	old_state[index] = now;
}

void clear_encoders()
{
	for (int i = 0; i < 5; i++)
	{
		encoders[i] = 0;
	}
}


/**
 * PCINT4 => PINB4
 * PCINT5 => PINB5
 * PCINT6 => PINB6
 * PCINT7 => PINB7
 * PCINT16 => PINK0
 * PCINT17 => PINK1
 * PCINT18 => PINK2
 * PCINT19 => PINK3
 * PCINT20 => PINK4
 * PCINT21 => PINK5
 */
void init_encoders()
{
	DDRB &= !(0b11110000);
	PCICR |= 0b00000101;
	PCMSK0 |= (1 << PCINT4) | (1 << PCINT5) | (1 << PCINT6) | (1 << PCINT7);
	PCMSK2 |= (1 << PCINT16) | (1 << PCINT17) | (1 << PCINT18) | (1 << PCINT19) | (1 << PCINT20) | (1 << PCINT21);
	clear_encoders();
}

ISR(PCINT0_vect)
{
	uint8_t state = 0;
	state = ((PINB & (1 << PINB5)) >> PINB5) << 1;
	state += (PINB & (1 << PINB4)) >> PINB4;
	encoders_state(state, 0);

	state = ((PINB & (1 << PINB7)) >> PINB7) << 1;
	state += (PINB & (1 << PINB6)) >> PINB6;
	encoders_state(state, 4);
}

ISR(PCINT2_vect)
{
	uint8_t state = 0;
	state = (PINK & (1 << PINK5)) >> PINK5;
	state += ((PINK & (1 << PINK4)) >> PINK4) << 1;
	encoders_state(state, 1);

	state = ((PINK & (1 << PINK1)) >> PINK1);
	state += ((PINK & (1 << PINK0)) >> PINK0) << 1;
	encoders_state(state, 3);

	state = (PINK & (1 << PINK3)) >> PINK3;
	state += ((PINK & (1 << PINK2)) >> PINK2) << 1;
	encoders_state(state, 2);

}

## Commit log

2021-02-11 [ADD] beg assembly, but how to write PORTB ?
2021-02-22 [ADD] beg pin registers
2021-02-23 [UPD] reverse pin direction
2021-02-23 [ADD] tests for pin manipulation
2021-02-23 [UPDT] upper case img folder
2021-02-24 [ADD] beg leds part
2021-02-25 [ADD] atmega2560 board change
2021-02-26 [ADD] leds flashing + beg music
2021-03-03 [ADD] bancal mais fait des trucs
2021-03-03 [ADD] Leds work
2021-03-04 premier test de multiple bouton
2021-03-04 [ADD] 88 leds poc
2021-03-05 [ADD] Can select led pins (PORT >= H not yet here)
2021-03-05 [ADD] Leds works (not PORT > H)
2021-03-05 [ADD] Some lignes for leds
2021-03-19 Button POC
2021-03-19 migration arduino -> avr
2021-05-10 j ai besoin d un timer
2021-05-13 [RM] Pin manipulation (Ram usage 84=>8%)
2021-05-31 Kicad shematics added
    [Led_set copy.sch, Led_set.sch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]
2021-06-02 [ADD] Buttons part
2021-06-03 [ADD] Encoders Parts
2021-06-03 [BEG] Encoders + Millis
2021-06-04 [FIX] Led matrix + Spi
    [ili9341_init.c, low_level_led_addressing.c, main.c]
2021-06-04 [ADD] Numbers on matrix, but encoders bugs
    [encoders.c, leds.h, main.c]
2021-06-05 SPI Working like hell <3
2021-06-07 [ADD] pin tmp
2021-06-07 [ADD] Encoders seems Ok
2021-06-07 [ADD] millis
2021-06-07 [ADD] draw timer state (game)
2021-06-08 Broken Games - 4 and 24hours
    [game.c, main.c]
2021-06-09 [ADD] Buttons Ticks + Pushed
2021-06-09 [FIX] Buttons is clicking
    [buttons.c]
2021-06-09 [FIX] Invert bitwise on is activate
    [buttons.c]
2021-06-10 [FIX] RPC and Cheers
    [game.c, main.c]
2021-06-10 [FIX] Press button to skip rules
    [game.c]
